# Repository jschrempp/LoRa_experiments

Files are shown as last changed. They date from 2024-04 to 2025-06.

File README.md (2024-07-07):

# LoRa_experiments
## Tests of LoRA module (RYLR998) ranging and low power.

The Reyax RYLR998 is an inexpensive LoRa "modem".  It can perform point to point wireless data communication with other such modules.

The RYLR998 contains both a LoRa chip and a low power microcontroller.  A host microcontroller communicates with an RLYR998 using
serial port "AT" commands, making the RYLR998 very easy to use.  In addition, the RYLR998 has a low power sleep mode that reduces current
draw to about 10 microamps.  The use of LoRa for long distance, low volume data communication along with the ability to sleep the module
when not transmitting suggests that these modules could be ideal for use as long range contact open/close sensors.

The purpose of the tests documented in this repository is to explore the RYLR998 module capabilities in two respects:

- Long range operation:  the ability of the module to successfully commmunicate from an outdoor location some distance from a house
into a receiver located inside of the house.

- Low power operation:  the ability of the module to be powered down when not needed to transmit a short message, in support
of battery powered operation.

There are two main folders in this repository:

- Range_Testing: this folder contains a report and source code for range testing experiments.

- Low_Power_Testing: this folder contains a report and source code for testing low power operation of the module. It also contains
a spreadsheet to calculate battery life, based upon using an Attiny85 as the host microcontroller with a reset pulse generator circuit 
to power it up for transmitting a short message and then powering the LoRa module down and then powering itself down until the next reset.

## LoRa set up ##
- LoRa AT command guide https://lemosint.com/wp-content/uploads/2021/11/Lora_AT_Command_RYLR998_RYLR498_EN.pdf
- LoRa module we use https://reyax.com/products/RYLR498

Note that for these tests you need to program each LoRa module by hand using a terminal emulator and an FTDI module. Connect four
pins from the FTDI to the LoRa module (leave the reset pin on the LoRa module unconnected):

```
FTDI       LoRa
3v3        VDD
TXD        RXD
RXD        TXD
GND        GND
```

Plug the FTDI device into your laptop.

You can use the Arduino IDE Serial Monitor. With the IDE running go to Tools / Port and select the port of your FTDI device (it might be 
something like `/dev/serial-1`). Then click the Serial Monitor button on the upper right of the Arduino IDE. This brings up a new window.
In the bottom menu select "Both NL & CR" and "115200 baud". In the command window at the top type AT and click Send. You should get the 
response +OK

Assuming you are now connected correctly to your LoRa module, perform the following commands:
```
AT+ADDRESS=0
AT+NETWORKID=3
```
Do the same for your second LoRa module.

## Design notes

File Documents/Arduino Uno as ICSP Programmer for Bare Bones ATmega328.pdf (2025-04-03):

# Arduino Uno as ICSP Programmer for Bare Bones ATmega328

By: Bob Glicksman; v1.0; 7/20/24 © 2024, Bob Glicksman, Jim Schrempp, Team Practical Projects. All rights reserved.

Introduction.

This document provides complete instructions for programming a “bare bones” ATmega328 (or ATmega328P) chip using “In Circuit Serial Programming” (ICSP). Bare-Bones means a factory-fresh chip that you will be using:

- With the internal 8 MHz clock (no crystal/capacitors for the external 16 MHz clock used on Uno and other Arduino boards).
- The chip does not come with a bootloader already flashed onto it.

The Arduino IDE (version 1.8.7) is used for both software development and for uploading compiled code to the chip. An Arduino Uno (R3) is used as the hardware ICSP programmer.

The information herein is based upon the official Arduino documentation that can be found at: https://docs.arduino.cc/built-in-examples/arduino-isp/ArduinoToBreadboard/

The Arduino documentation focuses on the use of ICSP to upload the Arduino bootloader to the bare bones chip. Thereafter, user-created programs are uploaded to the chip using the bootloader. This document describes a procedure that uses ICSP exclusively and overwrites the bootloader. There are several reasons for our wanting to do this:

- The bootloader takes up 512 bytes of the 32 Kbytes of flash memory on the ATmega328 chip. This is small and usually unimportant.
- When the bootloader is used, resetting the ATmega328 executes the bootloader first. When no new code is available for uploading (particularly when no programmer is attached to the chip’s serial I/O port), the bootloader times out before transferring control to the existing user’s program. The timeout delay is short, however this delay can be important for applications that are battery powered and use RESET to wake up from deep sleep, perform a small function, and then go back to deep sleep. Adding bootloader execution time to the regular wakeup execution time can significantly add to battery drain.
- The bootloader uses the (single) hardware serial port on the ATmega328. If the user’s application also uses the serial port, there can be a conflict if the chip is to be programmed in-circuit. Extra components will be necessary in the circuit to allow both an external serial programmer and the internal (to the project) circuitry to use the one hardware serial port without conflict.

This document describes the procedure to upload code to both the ATmega328 and the ATmega328P chips. The -P version of the chip can be powered down to a much lower power draw then the non-P version (< ⅓ microAmp as opposed to about 25 microAmps). The -P version also has a few more machine language instructions than does the non-P version, but this does not seem to make any difference when programming in the Arduino programming language (“Wiring”) using the Arduino IDE.

Hardware Requirements.

The following hardware is needed for this project:

- 1 ea. Arduino Uno (R3), or clone.
- 1 ea. Solderless breadboard.
- 2 ea. 0.1 uF decoupling capacitors.
- Male-male jumper wires
- ATmega328-PU or ATmega329P-PU microcontroller chips (without bootloader):
- non-P version: Digikey P/N ATMEGA328-PU-ND
- -P version: Digikey P/N ATMEGA328P-PU-ND
- (optional) 28 pin, 0.3” ZIF socket: Adafruit P/N 382
- (optional) 3 ea LED and 3 ea resistor (220 or 330 ohm) – wire per the instructions in the comments in the ArduinoISP program if you want these status indicators.

# Hardware Setup for Using Uno as ISP Using ICSP

Protocol.

The following figure shows how to wire an Arduino Uno to the breadboard in order to use it as an ISP. This figure is taken directly from the official Arduino documentation:

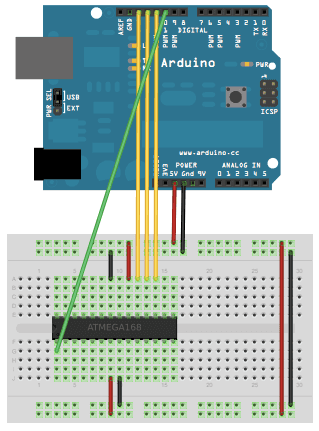
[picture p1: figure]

Here are the instructions:

1. Wire the breadboard power rails: Wire the + power bus on one side of the breadboard to the + power bus on the opposite side of the breadboard.
2. Wire the breadboard ground rails: Wire the - (gnd) power bus on one side of the breadboard to the - (gnd) power bus on the opposite side of the breadboard.
3. Wire the Uno GND pin to the closest - (gnd) power bus on the breadboard
4. Wire the Uno +5 volt power pin to the closest + power bus on the breadboard.
5. Place the target ATmega328 or ATmega328P chip on the breadboard, as shown in the diagram. OPTIONALLY, place a 28 pin ZIF socket where the ATmega is shown. Note that in the diagram above, ATmega pin 1 (notch at the top of the chip) is to the left.
6. Wire IC pin 7 to the closest + power rail.
7. Wire IC pin 8 to the closest - (gnd) power rail.

8. Place a 0.1 uF decoupling capacitor between IC pins 7 and 8, close to the power wiring to the chip.
9. Wire IC pin 20 to the closest + power rail.
10. Wire IC pin 22 to the closest - (gnd) power rail.
11. Place a 0.1 uF decoupling capacitor between IC pins 20 and 22, close to the power wiring to the chip.
12. Wire Uno digital pin 10 to pin 1 of the IC on the breadboard.
13. Wire Uno digital pin 11 to pin 17 of the IC on the breadboard.
14. Wire Uno digital pin 12 to pin 18 of the IC on the breadboard.
15. Wire Uno digital pin 13 to pin 19 of the IC on the breadboard.

TIP: If using the ZIF socket, then with a Sharpie marker, put four marks on the ZIF case at the pin position for each of the ends of the ZIF socket. This makes it easier to map ATmega chip pins to the solderless breadboard wire holes.

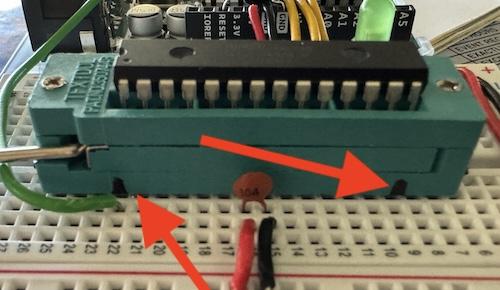
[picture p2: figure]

Overview of Operating Instructions.

Detailed operating instructions are presented in the next section of this document. Here is an overview of the entire process:

1. Install a “hardware/breadboard” folder into your Arduino Uno IDE sketchbook. This folder is necessary to tell the IDE about the chip that you are going to program. Optionally edit the file “boards.txt” to change from the default -P chip to the non-P version of the chip.

2. Open the Arduino IDE and upload the example sketch “ArduinoISP” to your Uno board. This makes your Uno into an ICSP programmer for your bare bones chips, using the wiring described above.
3. Flash the Arduino bootloader to the ATmega328(P).
4. Configure the Arduino IDE for programming the bare bones chip.
5. Compile and verify your program on the Arduino IDE.
6. Upload your program to the bare bones chip using ICSP.

NOTE: This procedure will flash the Arduino bootloader to the bare bones chip but will subsequently overwrite it. You need to flash the bootloader because this process also sets necessary fuses and locks on the bare bones chip. After executing this procedure in full the first time, you can skip steps 1-3 thereafter, as the fuses and locks will remain properly set. The bootloader program itself will be overwritten, but it is not needed when using this procedure. You can, however, always restore the bootloader to the bare bones chip by following steps 1-3 of this procedure.

Detailed Operating Instructions.

This section provides step by step detailed instructions for each of the steps listed above.

## 1. Install the “hardware/breadboard” folder into your Arduino

sketchbook.

You can find the location of your Arduino sketchbook using the Arduino IDE. Open the IDE and select “File : Preferences”. You will see the location of your sketchbook here:

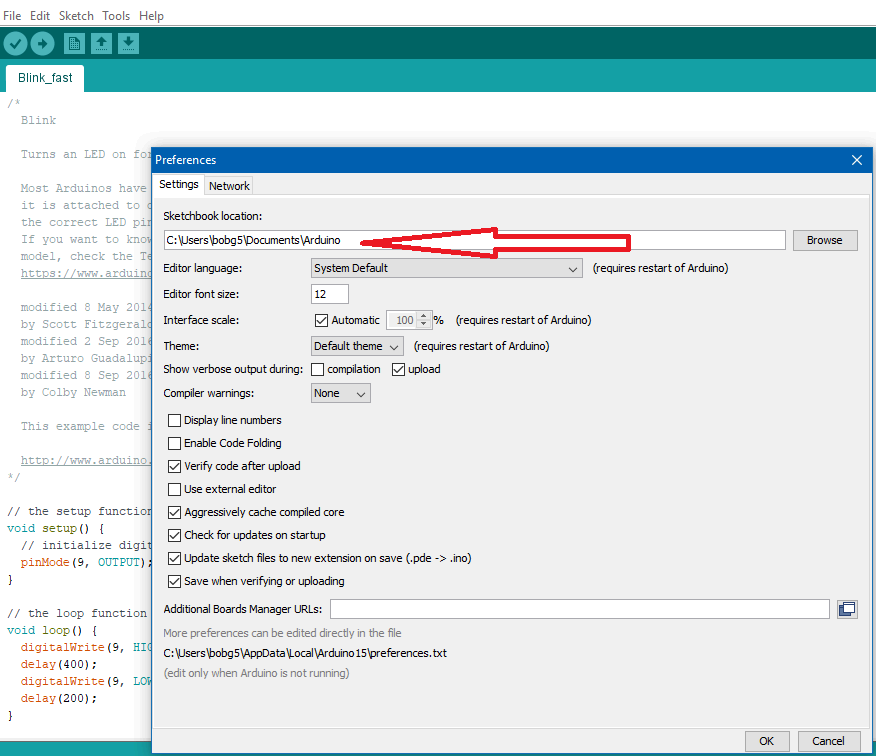
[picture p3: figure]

Open the sketchbook location on your computer using your computer’s file explorer. See if there is already a folder called “hardware” here. If not, create an empty folder called “hardware”.

Download the following zip file from the Arduino website: https://www.arduino.cc/en/uploads/Tutorial/breadboard-1-6-x.zip

Open this zip file and extract the contents. The contents will be a folder called “breadboard” with some subfolders and other files inside of it. Drag and drop the “breadboard” folder inside of the “hardware” folder in your Arduino sketchbook.

If you plan to use only the -P chips, then you don’t need to do anything else in this step. If you plan to use non-P chips, follow these additional steps:

- Open the “breadboard” folder that you just installed into the “hardware” folder in your Arduino sketchbook location.
- Open the “avr” folder.
- Open the file “boards.txt” in any text editor (e.g. Notepad on a Windows PC). It will look like the following figure:

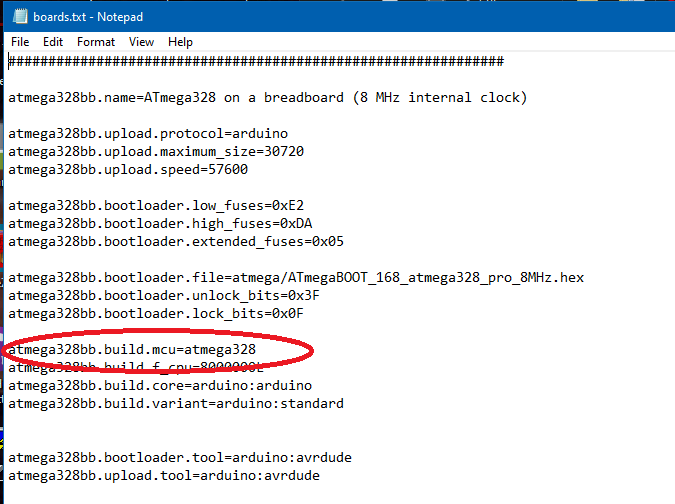
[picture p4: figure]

Note the circled line in the figure. The downloaded file will say “atmega328bb.build.mcu=atmega328p”. Note the “p” at the end of this line. This tells the Arduino IDE that the bare bones chip will be an ATmega328P chip. Remove the “p” at the end of this line (as shown in the figure) if you want to upload code to non-P chips. SAVE the edited file and exit your text editor.

## 2. Upload “ArduinoISP” Code to Your Uno to Make It Into An

In-System Programmer (ISP).

Open your Arduino IDE. If it is already open, you must close it and open it again.

As an optional first step, we recommend that you enable “verbose” status on the IDE when uploading code. Open the Arduino IDE preferences and check the “upload” check box, as shown in the figure below. Then click “OK” to exit the preferences.

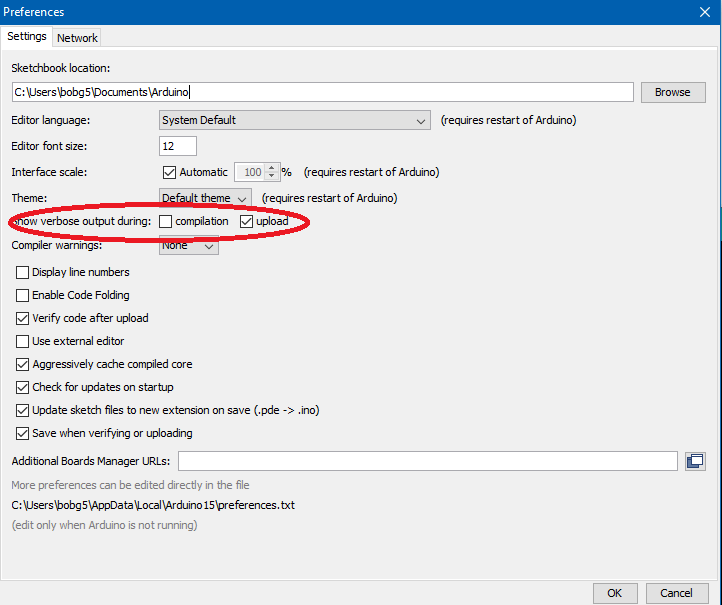
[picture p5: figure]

Next, you need to load the file “ArduinoISP” into the IDE, see the figure below. Select “File: Examples:11. ArduinoISP: ArduinoISP”. The IDE code window will show the source code for the Example file called “ArduinoISP”.

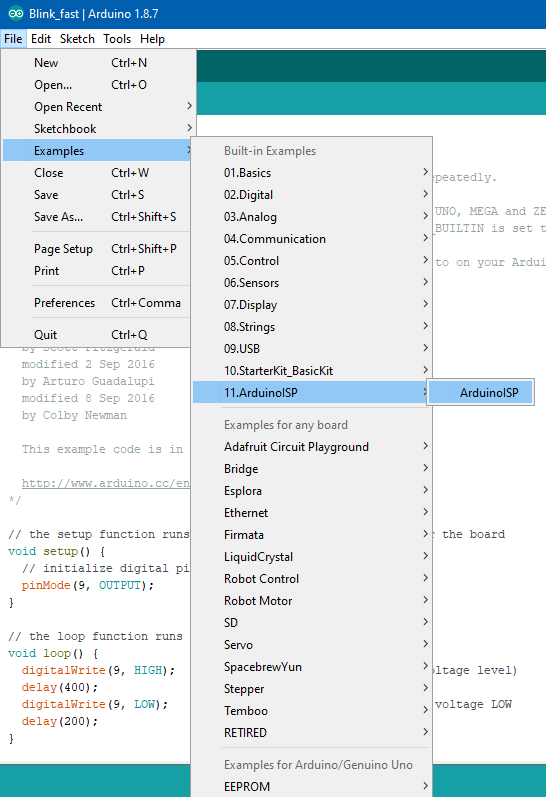
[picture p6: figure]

Before compiling and uploading “ArduinoISP” to your Uno board, make sure that your Tools settings are correct, see figure below:

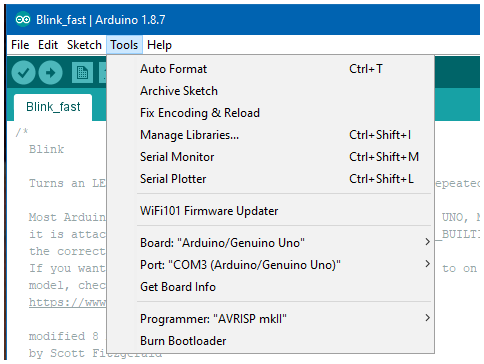
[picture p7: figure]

Note the following in this figure:

- The “Board:” must be “Arduino/Genuino Uno”
- The “Port” will be the COM or tty port that your Uno is connected to (may not be COM 3, as in the above figure).
- The “Programmer” must be set to “AVRISP mkII”.

After double checking these Tools settings, click on the Compile and Upload button: the Right facing arrow at the top left of the IDE window. This will flash the ArduinoISP code to your Uno. NOTE: You only need to do this once - thereafter, the ArduinoISP code will be running when you power up your Uno (unless you change it, of course).

3. Flash the Arduino Bootloader to the Bare Bones Chip.

You must next flash the Arduino bootloader to the bare bones chip. This step is necessary because it sets fuses and locks on the bare bones chip that are needed for the chip to operate properly. This step will also flash the bootloader program to your bare bones chip, but the bootloader will be overwritten in the subsequent steps of this procedure.

MAKE SURE THAT YOU HAVE YOUR BARE BONES CHIP PROPERLY INSERTED INTO YOUR BREADBOARD OR ZIF SOCKET. MAKE SURE THAT THE WIRING FROM THE UNO TO YOUR BREADBOARD IS CORRECT! MAKE SURE THAT YOU HAVE SET YOUR

BOARD.TXT FILE TO THE CORRECT CHIP (-P or non-P) PER THE FIRST STEP IN THIS DETAILED PROCEDURE.

Open the “Tools” menu on the Arduino IDE and go to “Board:” Look down the drop-down list for “ATmega328 on a breadboard (8 MHz internal clock)”, as shown in the figure below. Select “ATmega328 on a breadboard (8 MHz internal clock)” as the board to be programmed.

NOTE: if you don’t see this option, then go back to the initial step of this procedure where you installed the “hardware/breadboard” folder into your sketch folder using the downloaded zip archive. Repeat the steps, close the Arduino IDE and then reopen it. You should now see this Board option in your “Tools:Board” list.

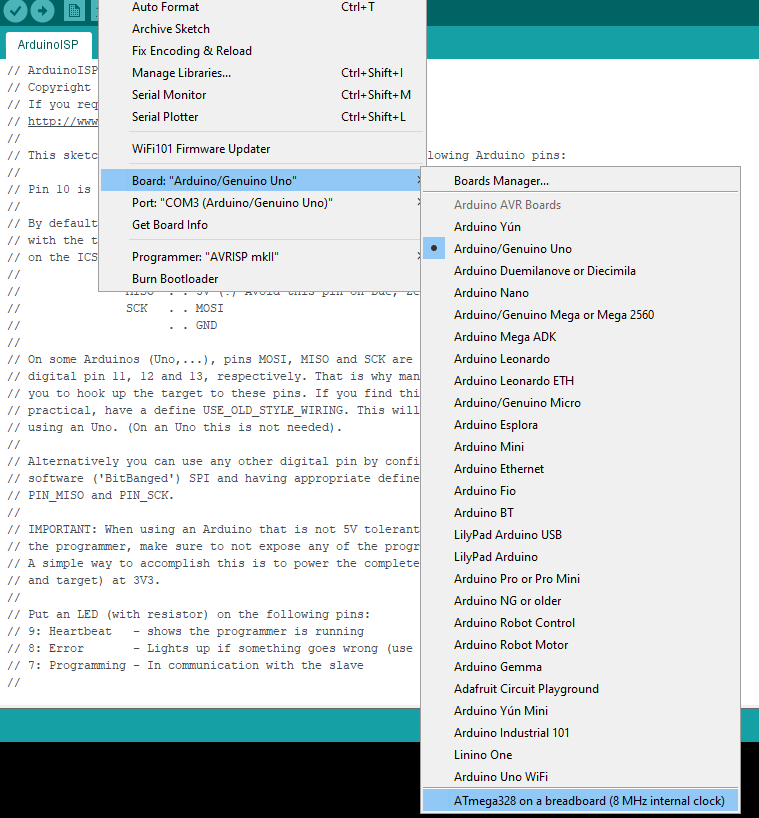
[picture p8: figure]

Next, go to “Tools” again and change the “Programmer” setting to “Arduino as ISP”

NOTE: do NOT confuse this with “ArduinoISP” which is also shown on the dropdown list. “ArduinoISP” is the program that you uploaded to your Uno in the previous step. In this step, you are selecting “Arduino as ISP” which tells the IDE to use your Uno as a programmer, rather than flashing new code to it.

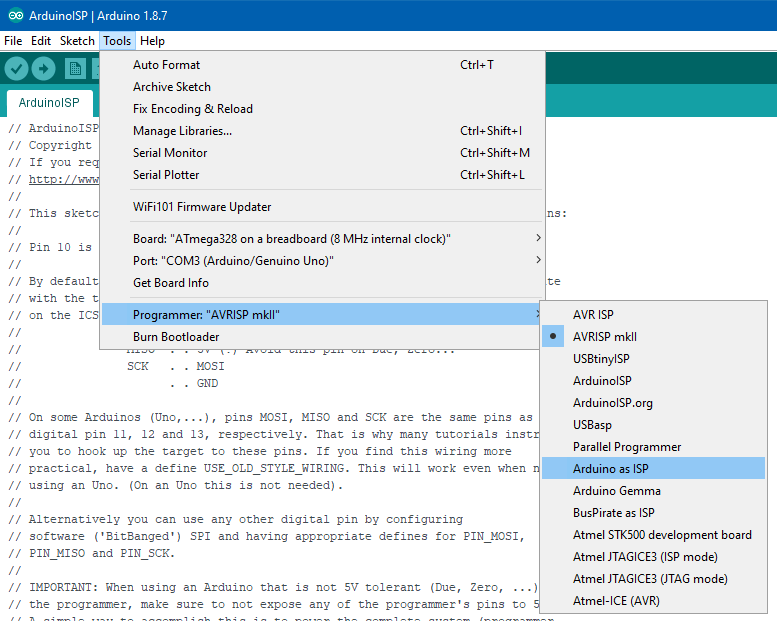
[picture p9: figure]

Before proceeding, verify all of your IDE settings, as in the figure below:

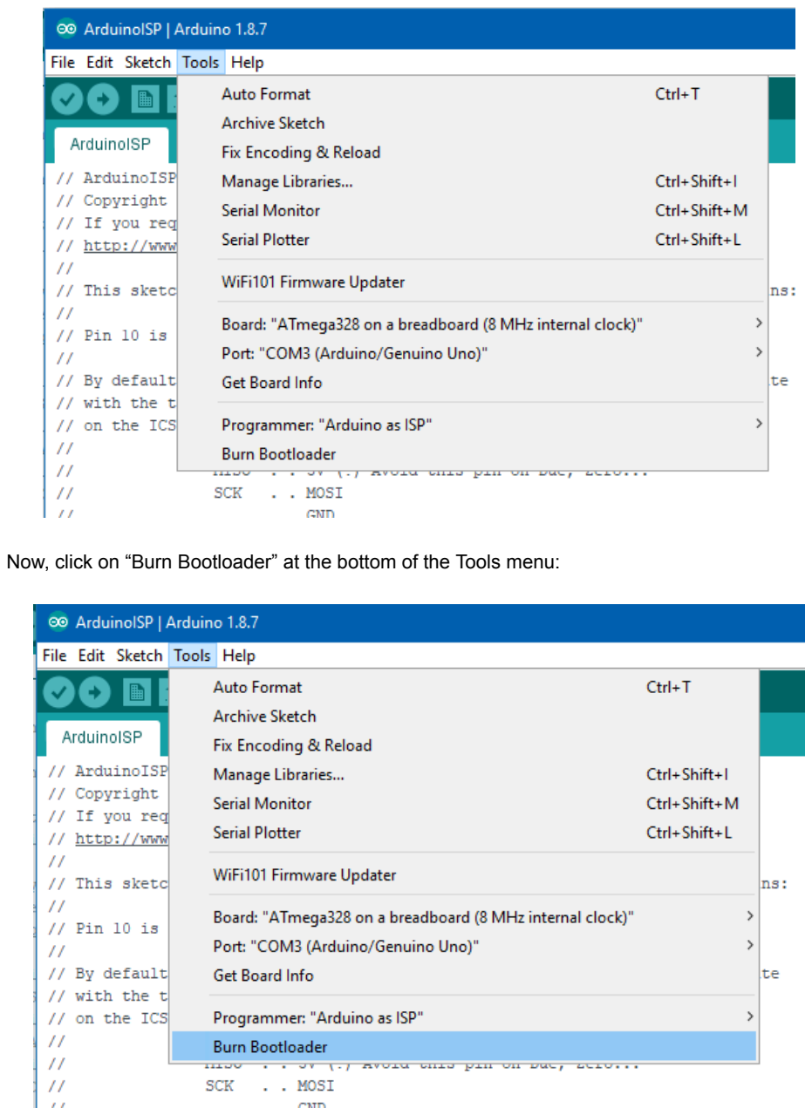
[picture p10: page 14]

Now, click on “Burn Bootloader” at the bottom of the Tools menu:

You will see the lights on the Uno flash for a bit while the fuses, locks and bootloader code are uploaded to your bare bones chip.

NOTE: if you get a signature error in the IDE status window, then you are probably configured for the wrong version of the ATmega328 chip (-P or not -P). Go back to the first step in this procedure and check the indicated line in the “boards.txt” file. Make the correction, save the file, close and open the IDE, and repeat this step.

## 4. Configure the Arduino IDE for ICSP Programming of a Bare

Bones Chip.

You should have the proper settings in the Tools menu, but you should verify this, as in the figure below:

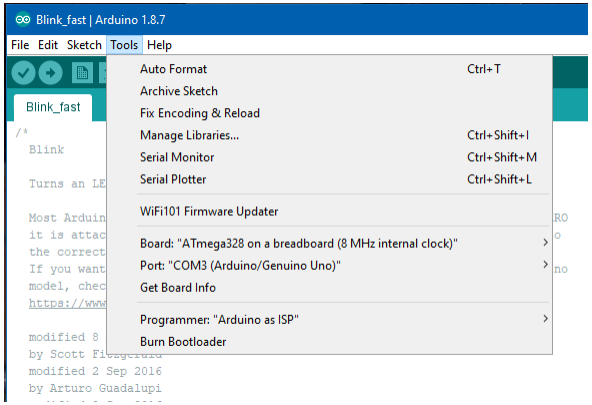
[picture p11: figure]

Double-check the following:

- “Board: ATmega328 on a breadboard (8 MHz internal clock)”
- “Port:” The COM or tty port that your Uno is connected to.
- “Programmer:” “Arduino as ISP”.

5. Compile and Verify Your Program on the Arduino IDE.

You are now ready to open or create a new program of your own that you want to upload to the bare bones chip. Proceed as you would for any program that you import, select, or create on the Arduino IDE. When your program is ready, you can compile and verify (but NOT upload) your code. You do this by clicking on the CHECK icon at the top left of the IDE (NOT the right arrow icon!), as shown in the figure below:

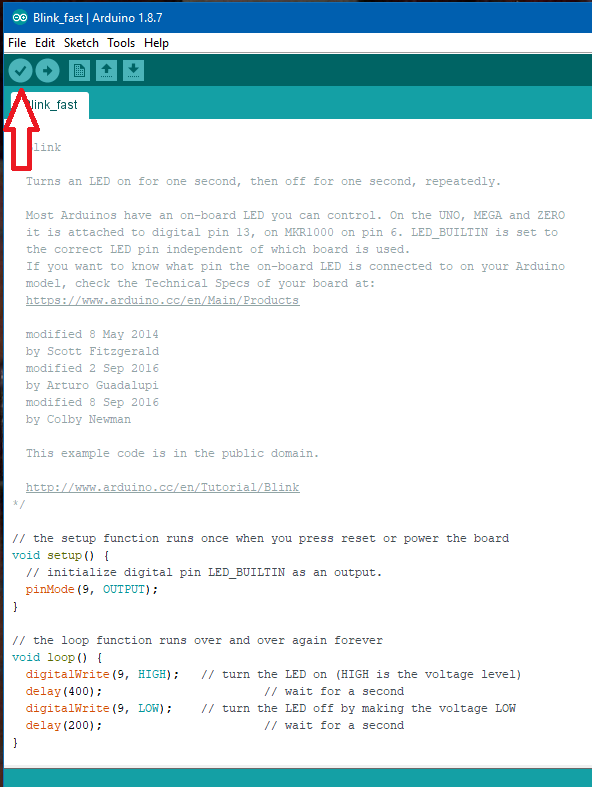
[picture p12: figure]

Check the status window on the IDE to make sure that your code has compiled and verified correctly!

6. Upload Your program to the Bare Bones Chip.

In order to upload your program to the bare bones chip using ICSP, you must open the “Sketch” menu on the Arduino IDE and select “Upload Using Programmer”:

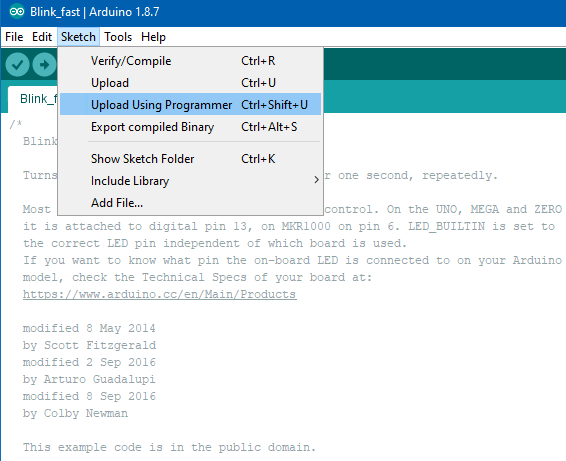
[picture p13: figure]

After a short delay, you will see lights flashing on the Uno indicating that it is working as an ICSP programmer and uploading your sketch to the bare bones chip.

At this point the ATmega will be executing code while in the programmer. One tip is to attach and LED and appropriate resistor to one digital pin and have your setup() code blink this once. That way you can verify in the programmer that your download has worked.

Subsequent Uploads to the Bare Bones Chip.

Once you have successfully completed all of these steps, you need not repeat steps 1-3 in order to modify the code and upload it to this same chip. You only need to perform steps 4 - 6, unless you (a) change the code flashed to your Uno, or (b) wish to restore the bootloader to your bare bones chip or (c) wish to upload code to another factory-fresh chip.

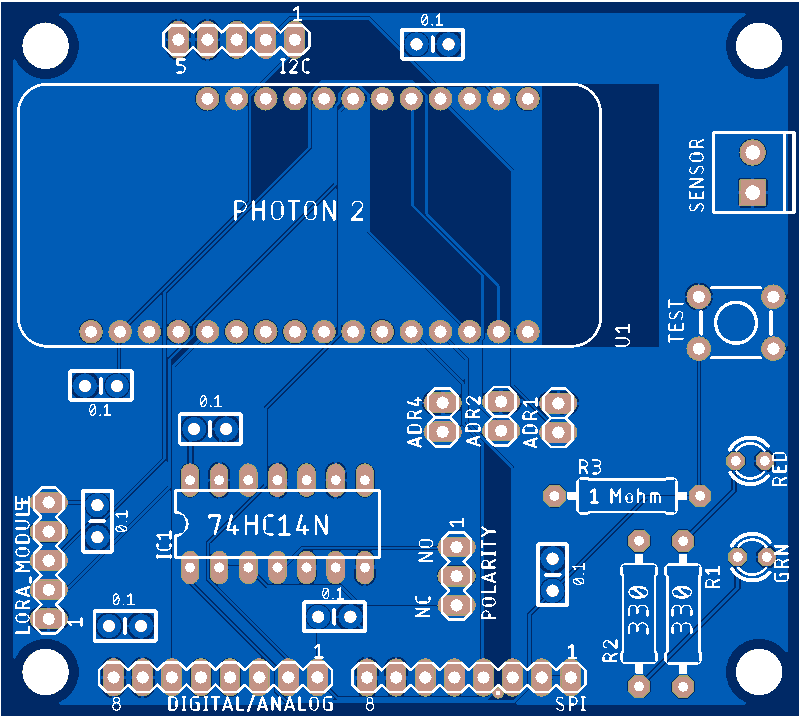
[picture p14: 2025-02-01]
Hardware/LoRa Photon 2 PCB/LoRa_Photon2/LoRa_Photon_2_pcb.png

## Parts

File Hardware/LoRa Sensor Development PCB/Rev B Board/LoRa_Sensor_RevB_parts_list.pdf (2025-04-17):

ITEM | PART NUMBER | MFG OR URL | DESCRIPTION | QTY | UNIT COST EXTENDED COST | NOTES | BG INV
1 Y10-2800069A | JLCPCB | Rev B PCB | 1 | $1.55 | $1.55 10 more boards on order 4/15/25 | 5

### 2 ATMega328P

https://www.digikey.com/en/products/detail/micro
chip-technology/ATMEGA328P-PU/1914589 | Microcontroller, 28 pin DIP | 1 | $2.89 | $2.89

I also have 5 non-P versions -- slightly higher
power but they work fine. | 4

### 3 Socket, 28 pin

https://www.amazon.com/uxcell-2-54mm-7-62mm-Soldering-Adaptor/dp/B07H3RP3JV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 En1ThlboPaV3COU4RK2hHrZodWnQ5sTGnGz4HQd hPUHrRxw2KXfZdHgG2wrHfeWkLYs1MahEdmNyZk X5PDTyATmnODv6ZC8hCcJhAyFBERcQ0ddlxnjp02lr vBw1igXjTKa5hQ.5xl5LLIRF56biPLH8kMX2m6P4R6x
adWV7I_maik6qSE&dib_tag=se&keywords=28+pin+
DIP+socket&qid=1744761481&sprefix=28+pin+dip+
socke%2Caps%2C183&sr=8-5 | 28 pin DIP socket | 1 | $0.33 | $0.33 URL is for 20 pcs | 5

4 74HC14N

https://www.digikey.com/en/products/detail/texas-
instruments/SN74HC14N/277223 | Hex CMOS inverter | 1 | $0.89 | $0.89 | 3

### 5 Socket, 14 pin

https://www.amazon.com/uxcell-2-54mm-Soldering-Socket-Adaptor/dp/B07H3WQYRQ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 EALaU3pVoE1LwHUuFkKhaxR6vCGmxljUArKusNRUKvnl A-VRif2UGHYDCarszrOfulmSilFftBcoGowjmH3BneBfIw08VRZCU3pqD1gH5IPZfksUx-Th7oCVgRJOAkPr0ZbPxcMwBGcvB7RXs0kBuCuzddkaqe6pv aMmh19ilpAqmxtK9S_RUCmzYH04kI61MIibgpgspT ph-lE0pbnwvU.icjyUkQsbgvTHvpMFriUBUrfxbnpt2abpGHPsOCUZE&dib_tag=se&keywords=14
+pin+DIP+socket&qid=1744761619&sprefix=14+pin
+dip+socket%2Caps%2C251&sr=8-3 | 14 pin DIP socket | 1 | $0.17 | $0.17 URL is for 40 pcs | 10

### 6 RYLR998

https://www.amazon.com/dp/B099RM1XMG?ref=p
px_yo2ov_dt_b_fed_asin_title | LoRa module, 915 MHz | 1 | $12.60 | $12.60 | 1

7 5 pin connector

https://www.amazon.com/Female-Headers-2-
54mm-Single-Connector/dp/B08T67RT8P/ref=sr_1_6?contentid=amzn1.sym.a076e7cd-4184-4b7f-a3aa-6a57a7570e58%3Aamzn1.sym.a076e7cd-4184-4b7f-a3aa-6a57a7570e58&dib=eyJ2IjoiMSJ9.W0noIfqcsOvUCs RPRRwNZXfyVjreQHL2MNQAJ4EujfEkHLjPAUFYlhJwSAAT Oqw8tPRzNHcji0S_ZDAC5sETtHQPYatDXWzzP7P4B gHGg5l8uANKXhAUtszp2dP-MSwPQGuekF0jzxb9frhymrgfgJAwerDD5t4o_6dezPi Po7uDH6ar0UxLD-688zKDWwRoDLLgyDu0ViZzyx46xEN1_ptV63gkwGy 0X4fQwhRq40kiiDrP_8gAjmt33lLFC4DRuA97B2REgj vWvVZkhVm77EkzLJznpqx-FmnRxQLEIo.TXHj_w6KZu4A8kWZA_GLvX_sk5QCdv BXxqjOEC565O0&dib_tag=se&keywords=5+pin+fe male+pin+header&pd_rd_r=d9221ee6-2e27-42cbb58cec69ec3b9ae2&pd_rd_w=Hnlr6&pd_rd_wg=DlvLf&q
| id=1744762468&sr=8-6 | 5 pin female header, 90 degree | 1 | $0.16 | $0.16 URL is for 50 pcs | 35
8 terminal block, 2 pin | https://www.adafruit.com/product/724 | 2 pin, 3.5 mm terminal block | 2 | $0.59 | $1.18 URL is for 5 pcs | 7
9 pcb switch | https://www.amazon.com/dp/B0DR2DPW59?ref=p
| px_yo2ov_dt_b_fed_asin_title&th=1 | pcb slide switch | 1 | $0.09 | $0.09 URL is for 80 switches | 50

### 10 pushbutton switch

Momentary-Tactile-Quality/dp/B01CGMP9GY/ref=sr_1_3?crid=1BT75H
D7EH7HV&dib=eyJ2IjoiMSJ9.JlRdu5IIhRb13BSG3- SPDT slide switch, 0.1 mm pitch | 2 | $0.05 | $0.11 URL is for 100 pcs | 30

### 11 male pin header

https://www.amazon.com/dp/B07R5QDL8D?ref=pp
x_yo2ov_dt_b_fed_asin_title

breakable male pin header, 40 pins, 2.54
| mm | 1 | $0.27 | $0.27 URL is for 20 strips, 40 pins each | 10

### 12 resistor, I Mohm

https://www.digikey.com/en/products/detail/stackp
ole-electronics-inc/CF14JT1M00/1741316 | 1 Mohm, 1/4W, through hole resistor | 1 | $0.10 | $0.10 | 5

### 13 resistor, 1 Kohm

https://www.digikey.com/en/products/detail/stackp
ole-electronics-inc/CF14JT1K00/1741314 | 1 Kohm, 1/4W, through hole resistor | 1 | $0.10 | $0.10 | 40

### 14 Red LED

https://www.amazon.com/Diode-Lights-120Pcs-Emitting-Assorted/dp/B0BY28JTFC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 Vkps4ikE12tjY0yF9U90AnTv6m9tKwqCMe8F2cgYOqu5T 5sBXjVYDNlY-SFkwtYLqvDdHWdlT6CYg4kvRYuNBcZLlcU0hRjYm3nSuWYLFPttIyTpxvkG3-yLnN6QtUinsVpc.4ApmabSVR-ZXlwQNI7db_pofeoIZTkJ5VvqVkDeOvY&dib_tag=se&keywords=red%2Bled%2B3mm&qi
d=1744762661&sprefix=red%2Bled%2B3mm%2Ca
| ps%2C200&sr=8-3&th=1 | Red LED, 3 mm | 1 | $0.04 | $0.04 URL is for 120 pcs | 20
15 Backlit pushbutton | https://www.adafruit.com/product/1440 | Green backlit pushbutton switch, panel
| | mount | 1 | $1.50 | $1.50 | 1
16 resistor, 330 ohm | https://www.digikey.com/en/products/detail/stackp
| ole-electronics-inc/CF14JT330R/1741399 | 330 ohm, 1/4W, through hole resistor | 2 | $0.10 | $0.20 | 11
17 capacitor, 100 uF | https://www.digikey.com/en/products/detail/rubyc
| on/35YXJ100M6-3X11/3563127 | 100 uF electrolytic capacitor, 10 volt | 1 | $0.20 | $0.20 | 20
18 capacitor, 0.1 uF | https://www.adafruit.com/product/753 | 0.1 uF ceramic capacitor, PCB | 10 | $0.20 | $1.95 URL is for 10 pcs | 11

### 19 battery holder

https://www.amazon.com/10Pcs-Battery-Holder-CR123A-Lithium/dp/B08RD1KQN3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 eH0mKLAfZkvZeiQh5MNyiY9QoTH6TeCB9N3-LZTDB4RAYLVbziLai-Lr8yBbOeQdnmwxl3hHAXRxzl58-XKznDxlBYJF7HMNiy2viXwkWCiiVrFQpaQjiLYxe83z9 kGSFdi18mduijg.MOh2SZFfu496f5C8bGMVPcgcCGmM5M
Koxda1s8jlcvs&dib_tag=se&keywords=123A+batter
y+holder&qid=1744762563&sprefix=123a+battery+
holder%2Caps%2C188&sr=8-1 | PCB battery holder for 123A battery | 1 | $0.80 | $0.80 URL is for 10 pcs | 5

### 20 battery, 3 volts

https://www.amazon.com/dp/B08YJQYD5Z?ref=ppx
_yo2ov_dt_b_fed_asin_title&th=1 | CR123A lithium 3 volts battery. | 1 | $1.97 | $1.97 URL is for 4 batteries | 1
TOTAL = | $27.10

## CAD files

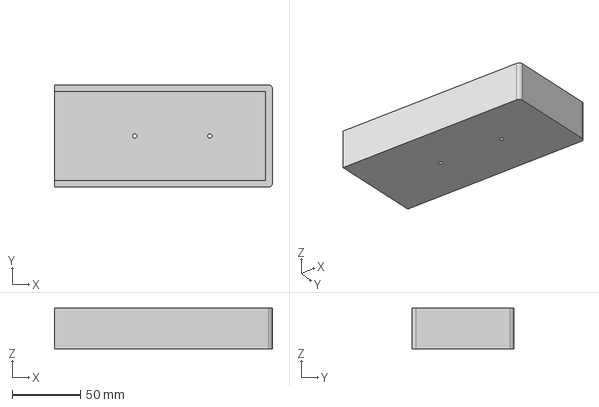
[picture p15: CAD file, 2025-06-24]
Hardware/Help Button Case/Wall Mount-2025-04-25-1.step
160.0 x 75.0 x 30.0 mm

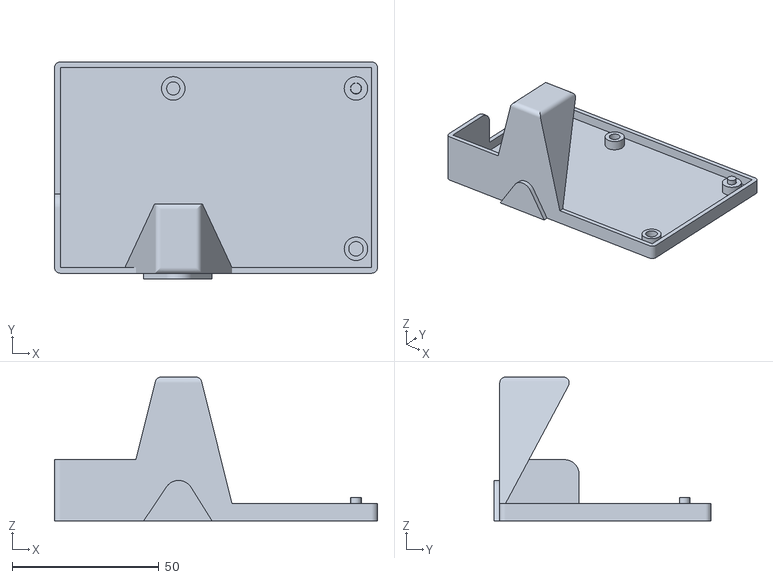
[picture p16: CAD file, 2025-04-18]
Hardware/Hub Case/LoRaHubCase.stl
110.0 x 74.0 x 49.0

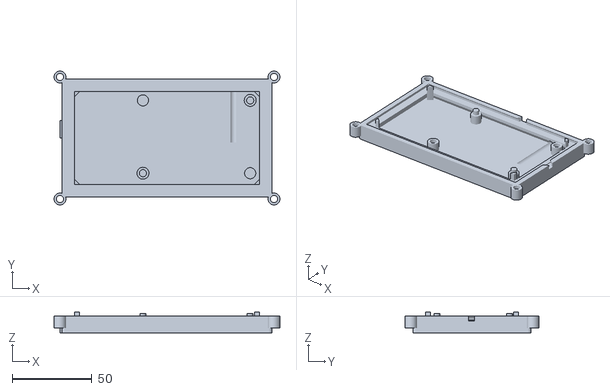
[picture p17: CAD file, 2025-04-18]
Hardware/Sensor Case/Bottom square.stl
141.8 x 84.1 x 13.0

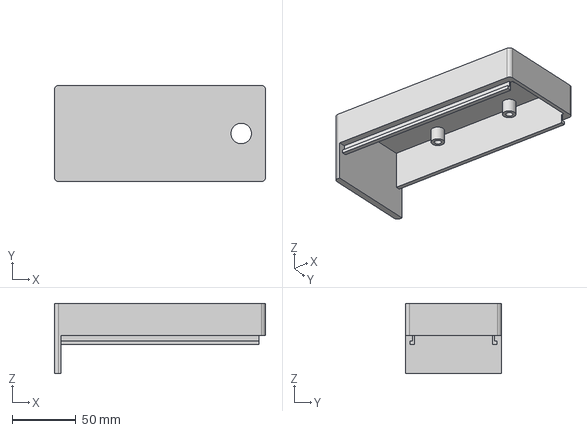
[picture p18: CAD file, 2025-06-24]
Hardware/Help Button Case/PCB Mount-2025-04-25-1.step
165.0 x 75.0 x 55.0 mm

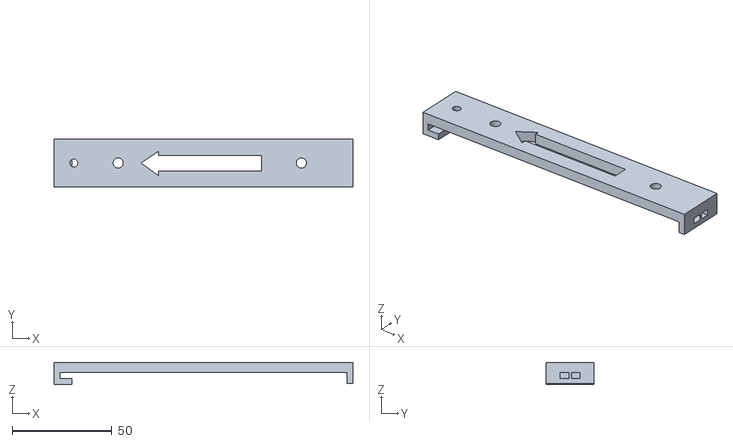
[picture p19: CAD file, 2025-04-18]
Hardware/Sensor Case/bracket.stl
150.0 x 24.0 x 11.2

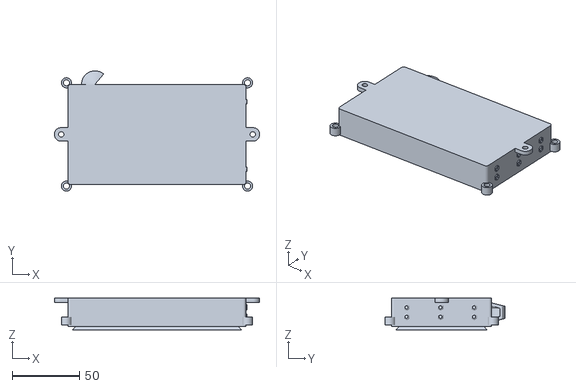
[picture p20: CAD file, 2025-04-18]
Hardware/Sensor Case/Top.stl
152.0 x 89.2 x 23.4

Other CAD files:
Hardware/Hub Case/LoRa_Hub_Case.f3d
Hardware/Sensor Case/LoRa_Sensor_Waterproof.f3d

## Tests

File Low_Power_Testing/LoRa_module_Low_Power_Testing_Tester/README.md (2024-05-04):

# Low_Power_Testing_Tester

This firmware project was created using [Particle Developer Tools](https://www.particle.io/developer-tools/) and is compatible with all [Particle Devices](https://www.particle.io/devices/).

Feel free to replace this README.md file with your own content, or keep it for reference.

## Table of Contents
- [Introduction](#introduction)
- [Prerequisites To Use This Template](#prerequisites-to-use-this-repository)
- [Getting Started](#getting-started)
- [Particle Firmware At A Glance](#particle-firmware-at-a-glance)
  - [Logging](#logging)
  - [Setup and Loop](#setup-and-loop)
  - [Delays and Timing](#delays-and-timing)
  - [Testing and Debugging](#testing-and-debugging)
  - [GitHub Actions (CI/CD)](#github-actions-cicd)
  - [OTA](#ota)
- [Support and Feedback](#support-and-feedback)
- [Version](#version)

## Introduction

For an in-depth understanding of this project template, please refer to our [documentation](https://docs.particle.io/firmware/best-practices/firmware-template/).

## Prerequisites To Use This Repository

To use this software/firmware on a device, you'll need:

- A [Particle Device](https://www.particle.io/devices/).
- Windows/Mac/Linux for building the software and flashing it to a device.
- [Particle Development Tools](https://docs.particle.io/getting-started/developer-tools/developer-tools/) installed and set up on your computer.
- Optionally, a nice cup of tea (and perhaps a biscuit).

## Getting Started

1. While not essential, we recommend running the [device setup process](https://setup.particle.io/) on your Particle device first. This ensures your device's firmware is up-to-date and you have a solid baseline to start from.

2. If you haven't already, open this project in Visual Studio Code (File -> Open Folder). Then [compile and flash](https://docs.particle.io/getting-started/developer-tools/workbench/#cloud-build-and-flash) your device. Ensure your device's USB port is connected to your computer.

3. Verify the device's operation by monitoring its logging output:
    - In Visual Studio Code with the Particle Plugin, open the [command palette](https://docs.particle.io/getting-started/developer-tools/workbench/#particle-commands) and choose "Particle: Serial Monitor".
    - Or, using the Particle CLI, execute:
    ```
    particle serial monitor --follow
    ```

4. Uncomment the code at the bottom of the cpp file in your src directory to publish to the Particle Cloud! Login to console.particle.io to view your devices events in real time.

5. Customize this project! For firmware details, see [Particle firmware](https://docs.particle.io/reference/device-os/api/introduction/getting-started/). For information on the project's directory structure, visit [this link](https://docs.particle.io/firmware/best-practices/firmware-template/#project-overview).

## Particle Firmware At A Glance

### Logging

The firmware includes a [logging library](https://docs.particle.io/reference/device-os/api/logging/logger-class/). You can display messages at different levels and filter them:

```
Log.trace("This is trace message");
Log.info("This is info message");
Log.warn("This is warn message");
Log.error("This is error message");
```

### Setup and Loop

Particle projects originate from the Wiring/Processing framework, which is based on C++. Typically, one-time setup functions are placed in `setup()`, and the main application runs from the `loop()` function.

For advanced scenarios, explore our [threading support](https://docs.particle.io/firmware/software-design/threading-explainer/).

### Delays and Timing

By default, the setup() and loop() functions are blocking whilst they run, meaning that if you put in a delay, your entire application will wait for that delay to finish before anything else can run. 

For techniques that allow you to run multiple tasks in parallel without creating threads, checkout the code example [here](https://docs.particle.io/firmware/best-practices/firmware-template/).

(Note: Although using `delay()` isn't recommended for best practices, it's acceptable for testing.)

### Testing and Debugging

For firmware testing and debugging guidance, check [this documentation](https://docs.particle.io/troubleshooting/guides/build-tools-troubleshooting/debugging-firmware-builds/).

### GitHub Actions (CI/CD)

This project provides a YAML file for GitHub, automating firmware compilation whenever changes are pushed. More details on [Particle GitHub Actions](https://docs.particle.io/firmware/best-practices/github-actions/) are available.

### OTA

To learn how to utilize Particle's OTA service for device updates, consult [this documentation](https://docs.particle.io/getting-started/cloud/ota-updates/).

Test OTA with the 'Particle: Cloud Flash' command in Visual Studio Code or the CLI command 'particle flash'!

This firmware supports binary assets in OTA packages, allowing the inclusion of audio, images, configurations, and external microcontroller firmware. More details are [here](https://docs.particle.io/reference/device-os/api/asset-ota/asset-ota/).

## Support and Feedback

For support or feedback on this template or any Particle products, please join our [community](https://community.particle.io)!

## Version

Template version 1.0.2

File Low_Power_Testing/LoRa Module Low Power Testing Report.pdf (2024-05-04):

# LoRa Module Low Power Testing Report

By: Bob Glicksman; 5/04/24
OVERVIEW.

This document describes the low power mode tests performed on the RYLR998 LoRa modules (https://reyax.com/products/RYLR998). These tests were performed in order to verify that these modules can be powered down to under 10 microamps when not being used to transmit data. Specifically, these tests verified that the modules can be powered up, then transmit a short message and then be powered down. This operation is necessary for a battery powered sensor, such as needed for the IVGM project.

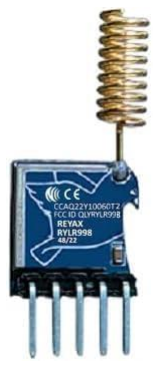
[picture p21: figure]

Figure 1. RYLR998 LoRa Modem Module.
RESULTS.

The RYLR998 LoRa modules were measured to draw about 17.5 milliamps when receiving (mode = 0) and about 8.5 microamps when in low power mode (mode = 1). When switching from mode 0 to mode 1, the module returns “+OK/r/n” and then powers down. When powered down, switching back to mode 0 returns “+OK/r/n” and the module powers up. Note that when in low power mode, sending a message (e.g. “AT+SEND=1,5,HELLO”) powers the module back up but returns “+MODE=0” as opposed to “+OK”. We think it best to explicitly power the LoRa module up before sending a message.

TESTING METHODOLOGY.

Mode and Power Testing.

An FTDI module was directly wired to an RYLR998 module as follows:

- FTDI GND to RYLR998 GND
- FTDI +3.3 to ammeter + (multimeter); ammeter – to RYLR998 VDD
- FTDI Tx to RYLR998 RXD
- FTDI Rx to RYLR998 TXD
- FTDI +5 unconnected
- RYLR998 NRST unconnected
The Arduino IDE Serial Monitor was used for communication. The current draw from the +3.3 volt power was measured by the multimeter on the 20 ma scale and also on the 200 microamp scale (lowest current scale available). The Serial Monitor was set to the RYLR998 default baud rate of 115200 and the end line set to both CR and LF, per the RYLR998 documentation; see:
https://reyax.com/products/RYLR998
Scroll down to “AT COMMAND MANUAL”.
The command “AT+MODE?” returned “+MODE=0”, which is consistent with the manufacturer’s documentation. The command “AT+SEND=1,5,HELLO” sent out this data, but the transmission was too quick to measure current draw on the ammeter. However, the ammeter did respond briefly, indicating that the current draw went way up when transmitting, consistent with the manufacturer’s data sheet.
The command “AT+MODE=1” returned “+OK/r/n” and the module powered down to 8.5 microamps. The command “AT+MODE=0” returned “+OK/r/n” and the module powered back up to 17.5 milliamps.
The command “AT+MODE=1” returned “+OK/r/n” and the module powered down to 8.5 microamps. The command “AT+SEND=1,5,HELLO” appeared to power the module back up and send out the message, but it returned “+MODE=0/r/n” in lieu of “+OK/r/n”.
These tests verify that the module powers up and powers down according to the manufacturer’s data.

Communication Testing with Power Switching.

These tests were performed to confirm the timing operation of powering up the LoRa module, sending out a short message, and then powering the module back down. It was performed in order to confirm that a command is complete and a new command to the module can be sent immediately after “+OK/r/n” is returned from the module to the microcontroller. In particular, we confirmed that we can power the LoRa module down immediately upon receiving “+OK/r/n” after a SEND command and that the LoRa transmission will be complete.
Two LoRa modules were pre-configured, as described below.

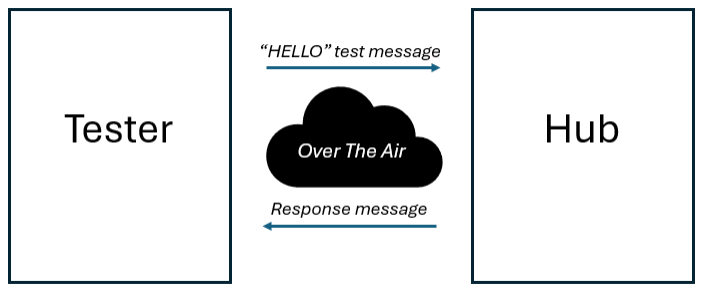
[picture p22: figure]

Figure 2. Range Testing Architecture.

The module designated for the “tester” was connected to a Particle Photon microcontroller that was programmed to send a short test message via the LoRa module whenever an onboard pushbutton was pressed. Specifically, the LoRa module is powered up, the test message is sent to the hub, and the LoRa module is powered down. The response message from the module (“+OK/r/n”) must always be received before a new command can be issued, but no further delays are required. Powering the LoRa module down was confirmed with an ammeter on the 3.3 volt power to the module.
The module designated for the “hub” is the same as the hub used for range testing. The hub’s LoRa module was connected to a Particle Photon microcontroller that was programmed to wait for receipt of a test message from the “tester” and, if a valid message was received, to transmit back a response message to the “tester” via its own LoRa module. The received message is also sent to a host computer via the Photon’s USB serial port and the message is displayed on a serial monitor for confirmation that the full and correct message was received.
Both the “tester” and the “Hub” were powered via USB on the Photon.
EQUIPMENT DESCIPTION.

Parts.

The following parts were used for these tests:

- 2 ea. RYLR998 LoRa Modem Modules. https://www.amazon.com/dp/B099RM1XMG?psc=1&ref=ppx_yo2ov_dt_b_product_details (https://www.amazon.com/dp/B099RM1XMG?psc=1&ref=ppx_yo2ov_dt_b_product_details)
- 1 ea. USB-Serial (“FTDI”) Module. https://www.amazon.com/dp/B00LODGRV8?psc=1&ref=ppx_yo2ov_dt_b_product_details (https://www.amazon.com/dp/B00LODGRV8?psc=1&ref=ppx_yo2ov_dt_b_product_details)
- 2 ea. Particle Photon modules. https://www.particle.io/. NOTE: The Photon is currently out of production; the Photon 2 may be used instead. The WiFi and BLE capabilities of the Photon/Photon 2 are not used for these tests and any 3.3 volt/USB powered Arduino board may be used.
- 1 ea. Breadboard compatible pushbutton switch.
- 2 ea. Solderless breadboard and male-male jumper wires.
- 1 ea. USB battery power supply.
- 1 ea. Multimeter.
Construction.

The figure below shows the “tester”:

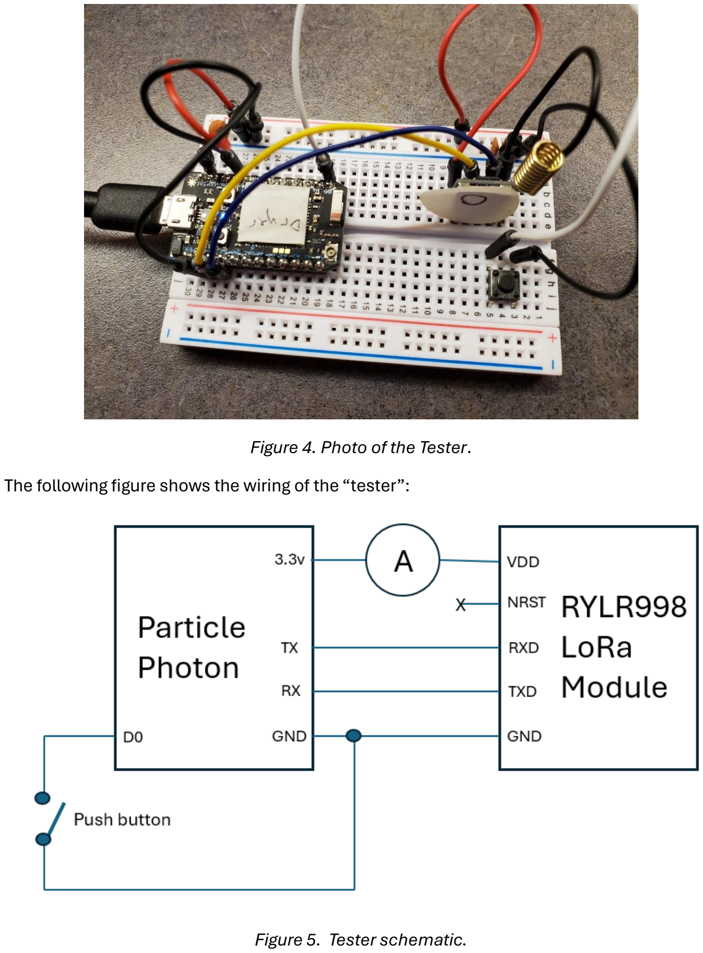
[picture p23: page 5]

Figure 4. Photo of the Tester. The following figure shows the wiring of the “tester”:

Figure 5. Tester schematic.

The Photon is powered through its onboard USB port. The Photon’s 3.3 volt output (from its on-board regulator) is used to power the LoRa module though an ammeter (multimeter on the DC amps setting). The Photon’s TX pin (Serial1 port) is connected to the LoRa module’s RXD pin and visa-vera. The LoRa module’s NRST (reset) pin is not connected.
The pushbutton switch has one end connected to the Photon D0 pin and the other end connected to ground.
The figure below shows the “hub”:

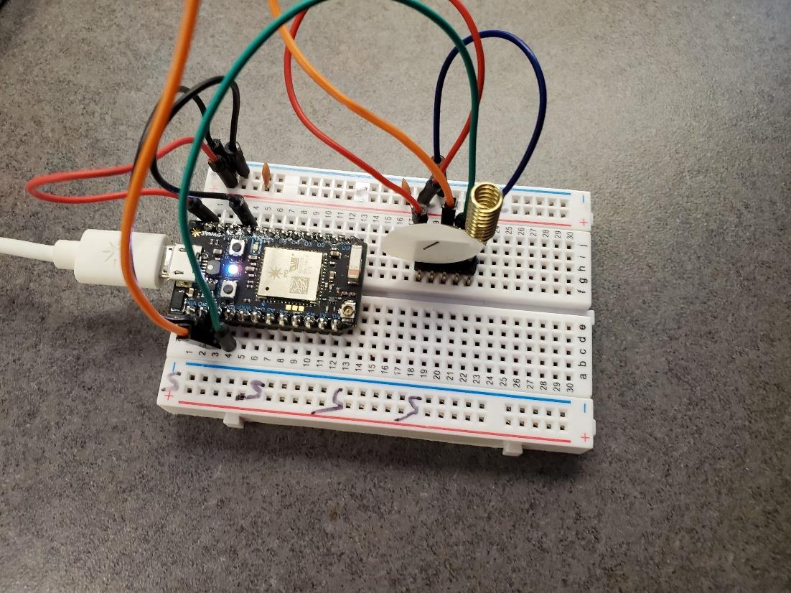
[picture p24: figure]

Figure 6. Photo of the Hub. The following figure shows the wiring of the “hub”:

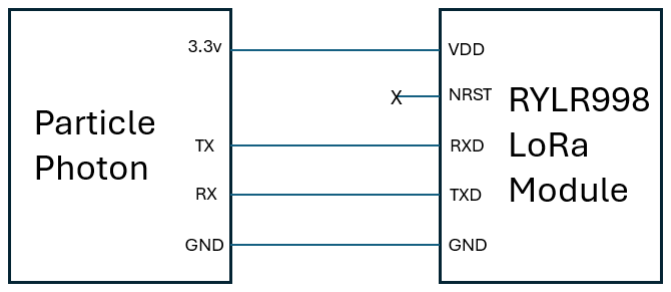
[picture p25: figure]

Figure 7. Hub Schematic.
The “hub” is the same (hardware and software) as for LoRa Range Testing.
SETUP AND CONFIGURATION.

The “hub” and “tester” software does not configure the LoRa modules. The modules must be set up using the USB-Serial module (“FTDI” module) and a PC running a terminal program. The terminal program used for these tests was the Arduino serial monitor; however, any terminal program will work.
The LoRa modules come “out-of-the-box” with a number of default settings. In general, the default settings were used for these tests. However, the module number and the network number were changed. The official documentation of the module AT command set can be found at:
https://reyax.com/products/RYLR998
Scroll down to “AT COMMAND MANUAL”.
The default baud rate for these LoRa modules is 115200 baud, and the default end-of-line is CR and LF (“/r/n”). In order to communicate with these modules using a terminal program on a PC, this baud rate and end-of-line settings must be used. Here are the settings used for these tests:

## Hub:

- Baud rate: 115200 (default)
- Mode: 0 (default)

- Band (for USA): 915 MHz (default)
- Network ID: 3
- Address: 0 (default)
- Parameters: (all default)
- Spreading factor: 9
- Bandwidth: 125 KHz
- Coding Rate: 1
- Preamble: 12

## Tester:

- Baud rate: 115200 (default)
- Mode: 0 (default)
- Band (for USA): 915 MHz (default)
- Network ID: 3
- Address: 1
- Parameters: (all default)
- Spreading factor: 9
- Bandwidth: 125 KHz
- Coding Rate: 1
- Preamble: 12
Note that only the network ID and the module address were changed from the defaults. The two modules must be set to different addresses, but they must both have the same network ID.
SOFTWARE DESCRIPTION.

The software (firmware) source code for the “hub” and “tester” is included in this repository. The software is well commented; hence only a brief description is given here.
Tester Software.

The “tester” software must operate independently of whether the “tester” can connect to WiFi. In order to use a Particle Photon, the “semi-automatic” system mode must be declared up front.

The “tester” software sets up things in setup(), including setting up D0 as INPUT_PULLUP and setting the Serial1 (LoRa module) baud rate for 115200. In loop(), the software tests for depression of the pushbutton. When the button is depressed, it :
1. Powers up the LoRa module (“AT+MODE=0”), and waits for the full OK message to be received.
2. Sends the “hello” message to the hub (“AT+SEND=1,5,HELLO”), and waits for the full OK message to be received.
3. Powers down the LoRa module (“AT+MODE=1”), and waits for the full OK message to be received.
4. Waits for the push button to be released, and then waits for it to again be depressed. NOTE: The “+OK” must be received from the LoRa module before a new command can be sent (according to the manufacturer’s documentation). We are not explicitly testing for “+OK/r/n”) because what would we do if we got an error instead? Rather, we simply wait for a complete response message from the LoRa module after each command is sent. A complete response is assured by setting Serial1.setTimeout(10); in setup(). With this setting, Serial1.readString(); keeps reading characters from the serial buffer and adding them to the received data string until there are no more characters for 10 milliseconds. This timeout should be more then long enough to assure that a complete response string has been received, event at a lower serial baud rate e.g. 9600 baud).

Hub Software.

The “hub” software is the same as for LoRa range testing. The “hub” software sets up things in setup(), setting the Serial1 (LoRa module) baud rate for 115200, and the Serial (USB) baud rate to 9600 (for debugging using a terminal program), and then enters loop(). In loop(), the software tests for data in the Serial1 receive buffer. If there is data in the buffer, is it read out and appended to a string variable to assemble the received message. Each time that data is added to the received message string variable, it is tested to see if the message is the test message from the “tester” (“HELLO”). If the test message has been received, the “hub” prints the received message to the USB serial port, sends out the response message back to the “tester”, and clears out the message string variable for another test.

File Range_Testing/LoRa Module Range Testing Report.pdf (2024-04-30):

# LoRa Module Range Testing Report

By: Bob Glicksman; 4/30/24
OVERVIEW.

This document describes the range tests performed on the RYLR998 LoRa modules (https://reyax.com/products/RYLR998). These tests were performed in order to verify that these modules meet the range requirements of the IVGM project. Specifically, these tests verified that the modules can successfully communicate between a mailbox located up to 100 feet in front of a house and a hub located just inside of the house.

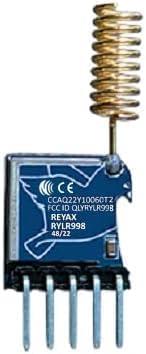
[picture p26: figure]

Figure 1. RYLR998 LoRa Modem Module.
RESULTS.

The RYLR998 LoRa modules easily met the project requirements; in fact, substantially exceeding them. Two range tests were performed:

1. The “hub” was placed in the back of the house. The “tester” was able to communicate with the hub at a distance of over 700 feet outside of the front of the house. Communication was successful over 700 feet of line of sight free air plus about 50 feet through many walls of the house.
2. The “hub” was placed in the front of the house, with only the front wall between the hub and outside free air. The “tester” was able to communicate with the hub at a distance of over 1000 feet outside of the front of the house. Communication was successful over 1000 feet of line of sight free air plus about 2 feet through the front wall of the house. Communication was lost when line of sight to the house was compromised by the street environment. It is possible that communication over longer distances would have been successful if there was a longer line of sight to the house in the test environment.

Additional, free air – line of sight tests may be conducted in the future.
TESTING METHODOLOGY.

Two LoRa modules were pre-configured, as described below.


Figure 2. Range Testing Architecture.

The module designated for the “tester” was connected to a Particle Photon microcontroller that was programmed to send a short test message via the LoRa module whenever an onboard pushbutton was pressed. The module designated for the “hub” was connected to a Particle Photon microcontroller that was programmed to wait for receipt of a test message from the “tester” and, if a valid message was received, to transmit back a response message to the “tester” via its own LoRa module. After sending out the test message, the “tester” waits three seconds and then reads out its LoRa module received response. If a valid response was received, the Photon microcontroller on the “tester” flashes its D7 LED three times. If no valid response message was received, the “test” flashes its D7 LED once. These tests were not performed at low power. The “hub” was powered from the AC mains by a USB power supply. Since the tester had to be operated outside, on the street, it was powered by a camping battery/inverter power source; see the figure below.

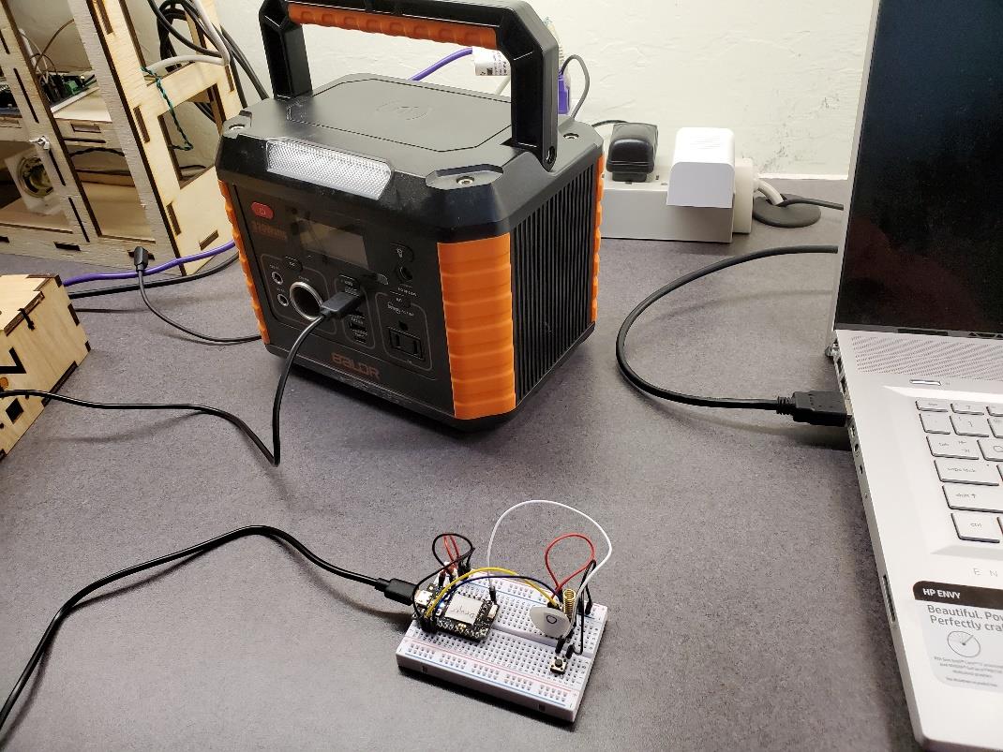
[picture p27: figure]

Figure 3. “Tester” and its portable power source. The “hub” was stationary while the “tester” was manually transported to various locations on the street at increasing distances from the house (but trying to keep line of sight to the house). At periodic intervals, the button on the “tester” was pressed and the D7 LED observed after the three second delay. Three flashes indicated successful communication while one flash indicated loss of communication. The point of loss of communication was noted on Google Maps and the Google Map scale was used to determine the distance from the house.
EQUIPMENT DESCIPTION.

Parts.

The following parts were used for these tests:

- 2 ea. RYLR998 LoRa Modem Modules. https://www.amazon.com/dp/B099RM1XMG?psc=1&ref=ppx_yo2ov_dt_b_product_details (https://www.amazon.com/dp/B099RM1XMG?psc=1&ref=ppx_yo2ov_dt_b_product_details)
- 1 ea. USB-Serial (“FTDI”) Module. https://www.amazon.com/dp/B00LODGRV8?psc=1&ref=ppx_yo2ov_dt_b_product_details (https://www.amazon.com/dp/B00LODGRV8?psc=1&ref=ppx_yo2ov_dt_b_product_details)

- 2 ea. Particle Photon modules. https://www.particle.io/. NOTE: The Photon is currently out of production; the Photon 2 may be used instead. The WiFi and BLE capabilities of the Photon/Photon 2 are not used for these tests and any 3.3 volt/USB powered Arduino board may be used.
- 1 ea. Breadboard compatible pushbutton switch.
- 2 ea. Solderless breadboard and male-male jumper wires.
- 1 ea. USB battery power supply.
Construction.

The figure below shows the “tester”:

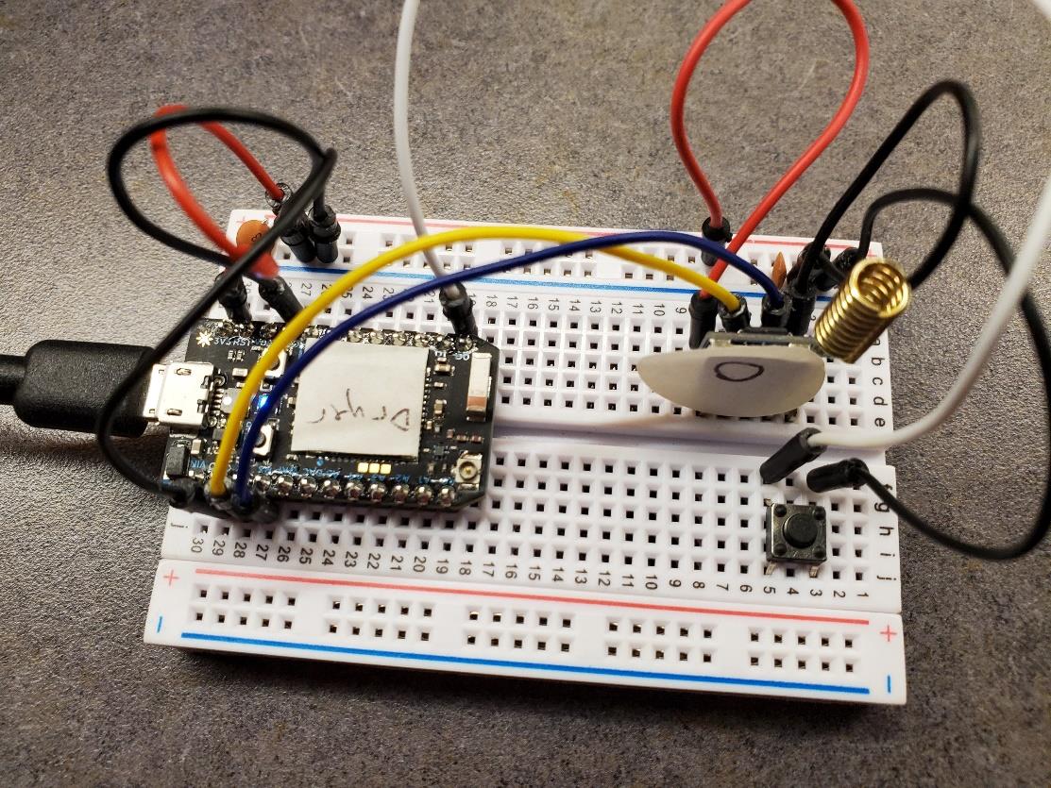
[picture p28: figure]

Figure 4. Photo of the Tester. The following figure shows the wiring of the “tester”:

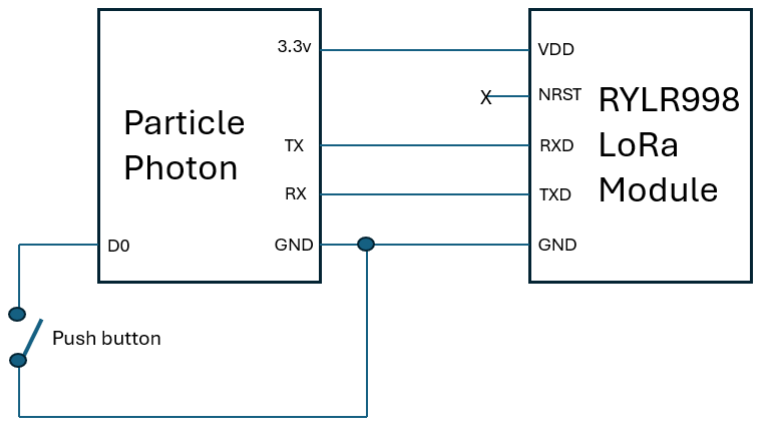
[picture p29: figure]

Figure 5. Tester schematic. The Photon is powered through its onboard USB port. The Photon’s 3.3 volt output (from its on-board regulator) is used to power the LoRa module. The Photon’s TX pin (Serial1 port) is connected to the LoRa module’s RXD pin and visa-vera. The LoRa module’s NRST (reset) pin is not connected.
The pushbutton switch has one end connected to the Photon D0 pin and the other end connected to ground.
The figure below shows the “hub”:

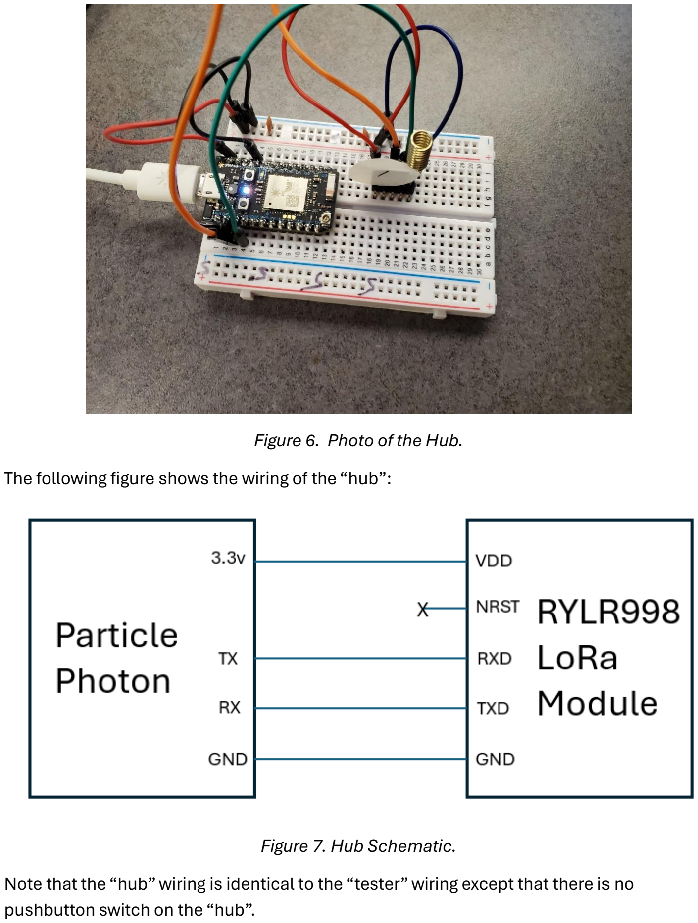
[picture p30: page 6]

Figure 6. Photo of the Hub. The following figure shows the wiring of the “hub”:

Figure 7. Hub Schematic.
Note that the “hub” wiring is identical to the “tester” wiring except that there is no pushbutton switch on the “hub”.

SETUP AND CONFIGURATION.

The “hub” and “tester” software does not configure the LoRa modules. The modules must be set up using the USB-Serial module (“FTDI” module) and a PC running a terminal program. The terminal program used for these tests was the Arduino serial monitor; however, any terminal program will work.
The LoRa modules come “out-of-the-box” with a number of default settings. In general, the default settings were used for these tests. However, the module number and the network number were changed. The official documentation of the module AT command set can be found at:
https://reyax.com/products/RYLR998
Scroll down to “AT COMMAND MANUAL”.
The default baud rate for these LoRa modules is 115200 baud, and the default end-of-line is CR and LF. In order to communicate with these modules using a terminal program on a PC, this baud rate and end-of-line settings must be used. Here are the settings used for these tests:

## Hub:

- Baud rate: 115200 (default)
- Mode: 0 (default)
- Band (for USA): 915 MHz (default)
- Network ID: 3
- Address: 0 (default)
- Parameters: (all default)
- Spreading factor: 9
- Bandwidth: 125 KHz
- Coding Rate: 1
- Preamble: 12

## Tester:

- Baud rate: 115200 (default)
- Mode: 0 (default)
- Band (for USA): 915 MHz (default)
- Network ID: 3

- Address: 1
- Parameters: (all default)
- Spreading factor: 9
- Bandwidth: 125 KHz
- Coding Rate: 1
- Preamble: 12
Note that only the network ID and the module address were changed from the defaults. The two modules must be set to different addresses, but they must both have the same network ID.
SOFTWARE DESCRIPTION.

The software (firmware) source code for the “hub” and “tester” is included in this repository. The software is well commented; hence only a brief description is given here.
Tester Software.

The “tester” software must operate independently of whether the “tester” can connect to WiFi. In order to use a Particle Photon, the “semi-automatic” system mode must be declared up front.
The “tester” software sets up things in setup(), including setting up D0 as INPUT_PULLUP, setting the Serial1 (LoRa module) baud rate for 115200, and the Serial (USB) baud rate to 9600 (for debugging using a terminal program), and then enters loop(). In loop(), the software tests for depression of the pushbutton. When the button is depressed, it sends out the “HELLO” message to the hub and sets a flag to expect a response from the hub. The code then waits for 3 seconds, after which the received data is read. The received data contains both the local response from the module’s sending command (“+OK” CR/LF) and any received response message (after 3 seconds). The code tests for “+RCV” in the message buffer to detect receipt of a response message. If a response message was received within 3 seconds, the D7 LED is flashed three times; otherwise it is flashed once. The code then waits for the pushbutton to be released, after which loop() repeats, waiting for the button to be pressed once again.

Hub Software.

The “hub” software sets up things in setup(), setting the Serial1 (LoRa module) baud rate for 115200, and the Serial (USB) baud rate to 9600 (for debugging using a terminal program), and then enters loop(). In loop(), the software tests for data in the Serial1 receive buffer. If there is data in the buffer, is it read out and appended to a string variable to assemble the received message. Each time that data is added to the received message string variable, it is tested to see if the message is the test message from the “tester” (“HELLO”). If the test message has been received, the “hub” sends out the response message back to the “tester” and clears out the message string variable for another test.
HOW THE LORA MODULES COMMUNICATE.

The LoRa modules communicate using “AT” commands, as specified in the manufacturer's “AT COMMAND MANUAL”, which can be found at: https://reyax.com/products/RYLR998 Here is a capture of communication between the “tester” and the “hub”.


Figure 8. screen captures of communication. Referring to figure 8, “COM 6” is from the “tester” and “COM 4” is from the “hub”.
The “tester” sends out its “HELLO” message after the button is pushed. The command to the LoRa module is:
“AT+SEND=1,5,HELLO”
All LoRa modules commands begin with “AT+”. The “SEND” command is to transmit data. The “1” parameter is the address of the intended recipient (in this case, 1 is the address set on the “hub” LoRa module). The next parameter is the size of the message. It is “5” because “HELLO” has 5 characters.
The “hub” receives this message, as shown in “COM 4”:
“+RCV=0,5,HELLO,-37,11”

“+RCV=” is what the LoRa module uses to designate a received message. “0” is the address of the module that sent the message (in this case, “0” is the address of the “tester”). “5”is the length of the received message and “HELLO” is the received message itself. The remaining two parameters are RSSI and SNR – these relate to the quality of the received signal (see the AT COMMAND MANUAL for details).
Referring to “COM 4”, the “hub”, having received a correct test message, sends out its response message (message data: “TEST”). The “hub” then receives “+OK” – this is a local response from the local LoRa module to the SEND command.

Referring back to “COM 6”:
The received data (after three seconds) contains the following:
“+OK CR/LF +RCV=1,4,TEST,-26,10 CR/LF”
This response is a little complicated. The first part: “+OK CR/LF” is the local response from the local LoRa module to the original “HELLO” message SEND command. This part means that the command was accepted by the LoRa module OK.
(p.s. – it is currently unclear whether +OK means that the AT string was formatted properly, that the send command was sent to the LoRa chip OK, or whether the LoRa chip transmitted the command in a proper LoRa packet, or even that the message was acknowledged by the receiver. More testing and investigation needs to be done here).
The remainder of the message string is the message data received from the “hub”: “+RCV=” designates that this is a received message.
“1” is the address of the sender of the message (the “hub”, in this case). “4” is the length (in bytes) if the message (length of “TEST”).
“TEST” is the message itself.
The remaining two parameters are RSSI and SNR – these relate to the quality of the received signal (see the AT COMMAND MANUAL for details).
Figure 8 shows two sets of test message send, receive and respond.

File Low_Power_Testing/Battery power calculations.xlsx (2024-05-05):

Number of sensor activations per day: | 3 | ea | mailman + me + one other
Battery capacity | 1500 | ma-hr | Energizer 123
Active LoRa power - transmitting | 140 | ma | per data sheet
Active LoRa power - receiving/waiting | 17.5 | ma | per data sheet
Quiescent LoRa power | 0.01 | ma | 10 microamps, per data sheet
Actvice ATtiny85 power | 2 | ma | per data sheet
Sleep (Quiescent) ATtiny85 power | 0.002 | ma | 2 microamp, data sheet
Quiescent switch pullup power | 0.003 | ma | 3 microamp - calculated
Quiescent reset pulse logic power | 0.04 | ma | 40 microamp max, per datasheet
Active sensor transmission time: | 165 | ms | from https://www.thethingsnetwork.org/airtime-calculator
Overhead time (sensor powered up but not X-mitting):
power up message + OK response + 10 ms timeout | 26 | ms | assume about 1 ms per chacrater (9600 baud)
transmitted message + OK response + 10 ms timeout | 34 | ms | assume about 1 ms per chacrater (9600 baud)
power down message + OK response + 10 ms timeout | 26 | ms | assume about 1 ms per chacrater (9600 baud)
add a few misc milliseconds | 10 | ms
Calculate Quiescent Current Draw: | 0.055 | ma | reset pulse gen + pullup + Attiny + LoRa quiescnet current
Calculate Quiescent Power: | 0.055 | ma-hr | quiescent power draw is continuous
Calculate Active Power Draw:
LoRa transmitting power when transmitting: | 23100 | ma-ms
LoRa transmitting power when transmitting: | 0.006416666667 | ma-hr
Total of all LoRa transmission power per day : | 0.01925 | ma-hr / day
Total overhead time (receiving): | 96 | ms
LoRa current draw receiving mode: | 1680 | ma - ms
LoRa power draw receiving mode: | 0.0004666666667 | ma-hr
LoRa power draw receiving mode per day: | 0.0014 | ma-hr/day
Total active Attiny time: | 261 | ms
Attiny active power draw: | 522 | ma-ms
Attiny active power draw: | 0.000145 | ma-hr
Total Attiny power draw / day expressed in hours: | 0.000435 | ma-hr/day
Total active power draw per day: | 0.021085 | ma-hr/day
Total power draw per day: | 1.341085 | ma-hr/day | quiescent power drawn 24 hr/day plus active power draw/day
Total days battery life: | 1118.497336 | days of life
Total Years Battery Life: | 3.062278812 | YEARS | NOTE: most of this is quiescent power - not that sensitive to active power!

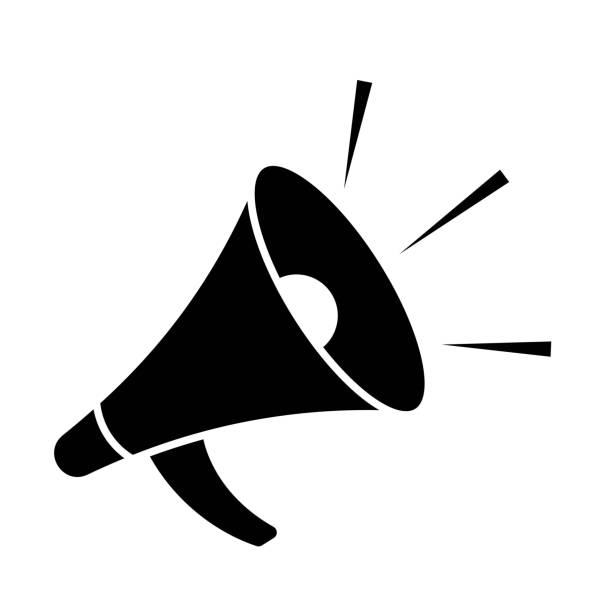
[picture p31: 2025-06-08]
Range_Testing/Range_Test_Hub/Clip Play App/Announcement.jpg

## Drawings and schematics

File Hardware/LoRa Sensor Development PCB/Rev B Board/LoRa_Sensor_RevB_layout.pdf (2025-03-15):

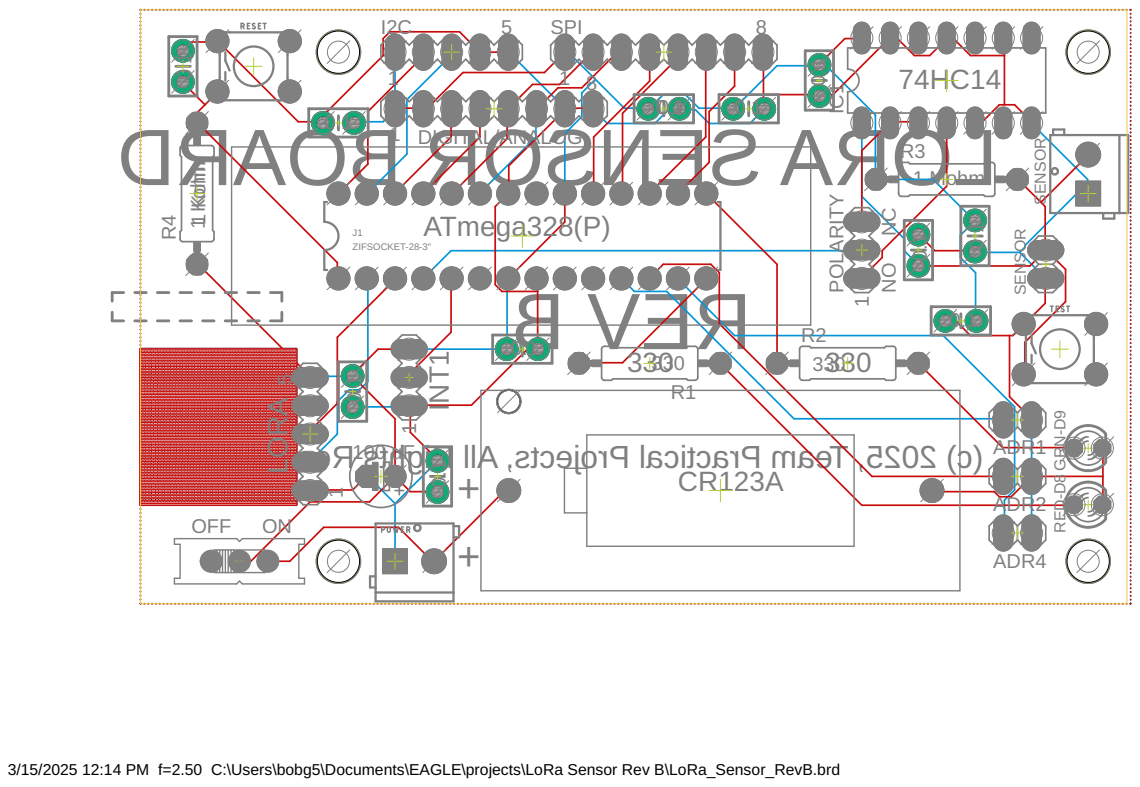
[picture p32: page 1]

3/15/2025 12:14 PM f=2.50 C:\Users\bobg5\Documents\EAGLE\projects\LoRa Sensor Rev B\LoRa_Sensor_RevB.brd

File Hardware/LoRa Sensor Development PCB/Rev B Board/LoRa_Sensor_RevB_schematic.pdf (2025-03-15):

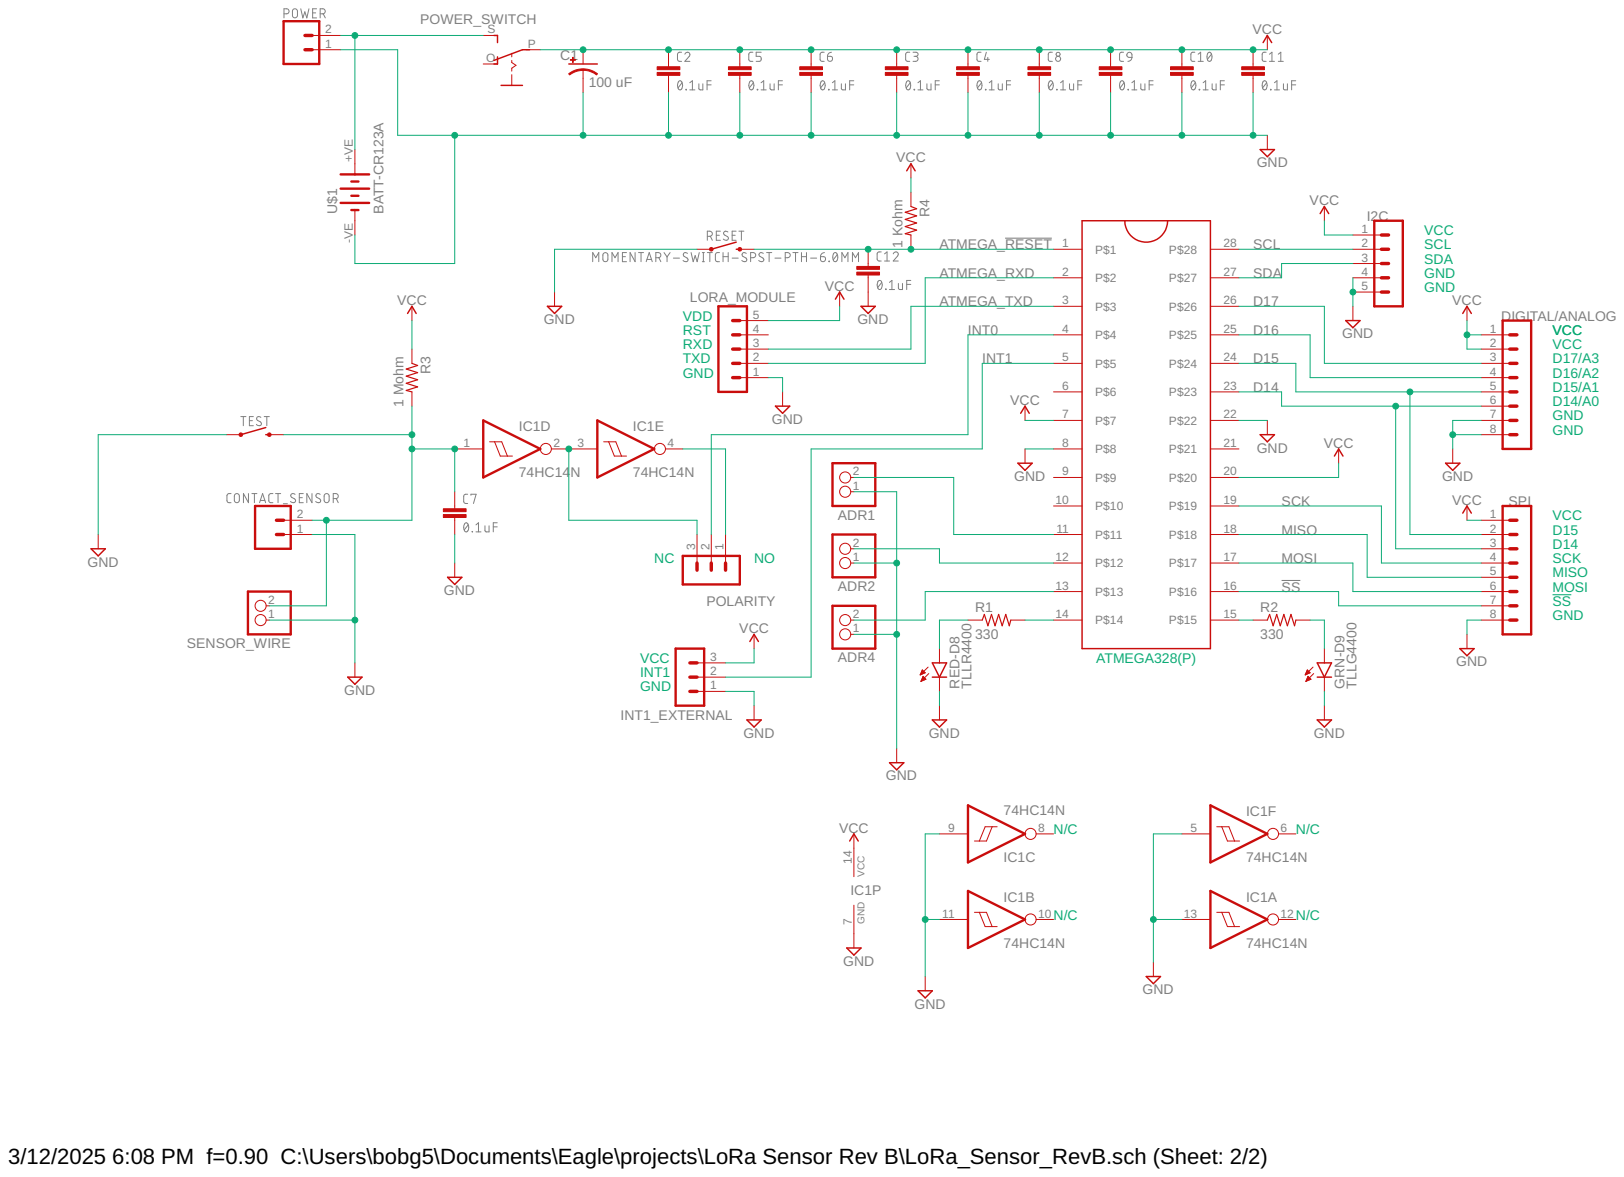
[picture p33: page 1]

GND
SCL SDA D17 D16 D15 D14 SCK MISO MOSI SS

VCC
SCL SDA GND GND

D15 D14 SCK MISO MOSI SS

3/12/2025 6:08 PM f=0.90 C:\Users\bobg5\Documents\Eagle\projects\LoRa Sensor Rev B\LoRa_Sensor_RevB.sch (Sheet: 2/2)

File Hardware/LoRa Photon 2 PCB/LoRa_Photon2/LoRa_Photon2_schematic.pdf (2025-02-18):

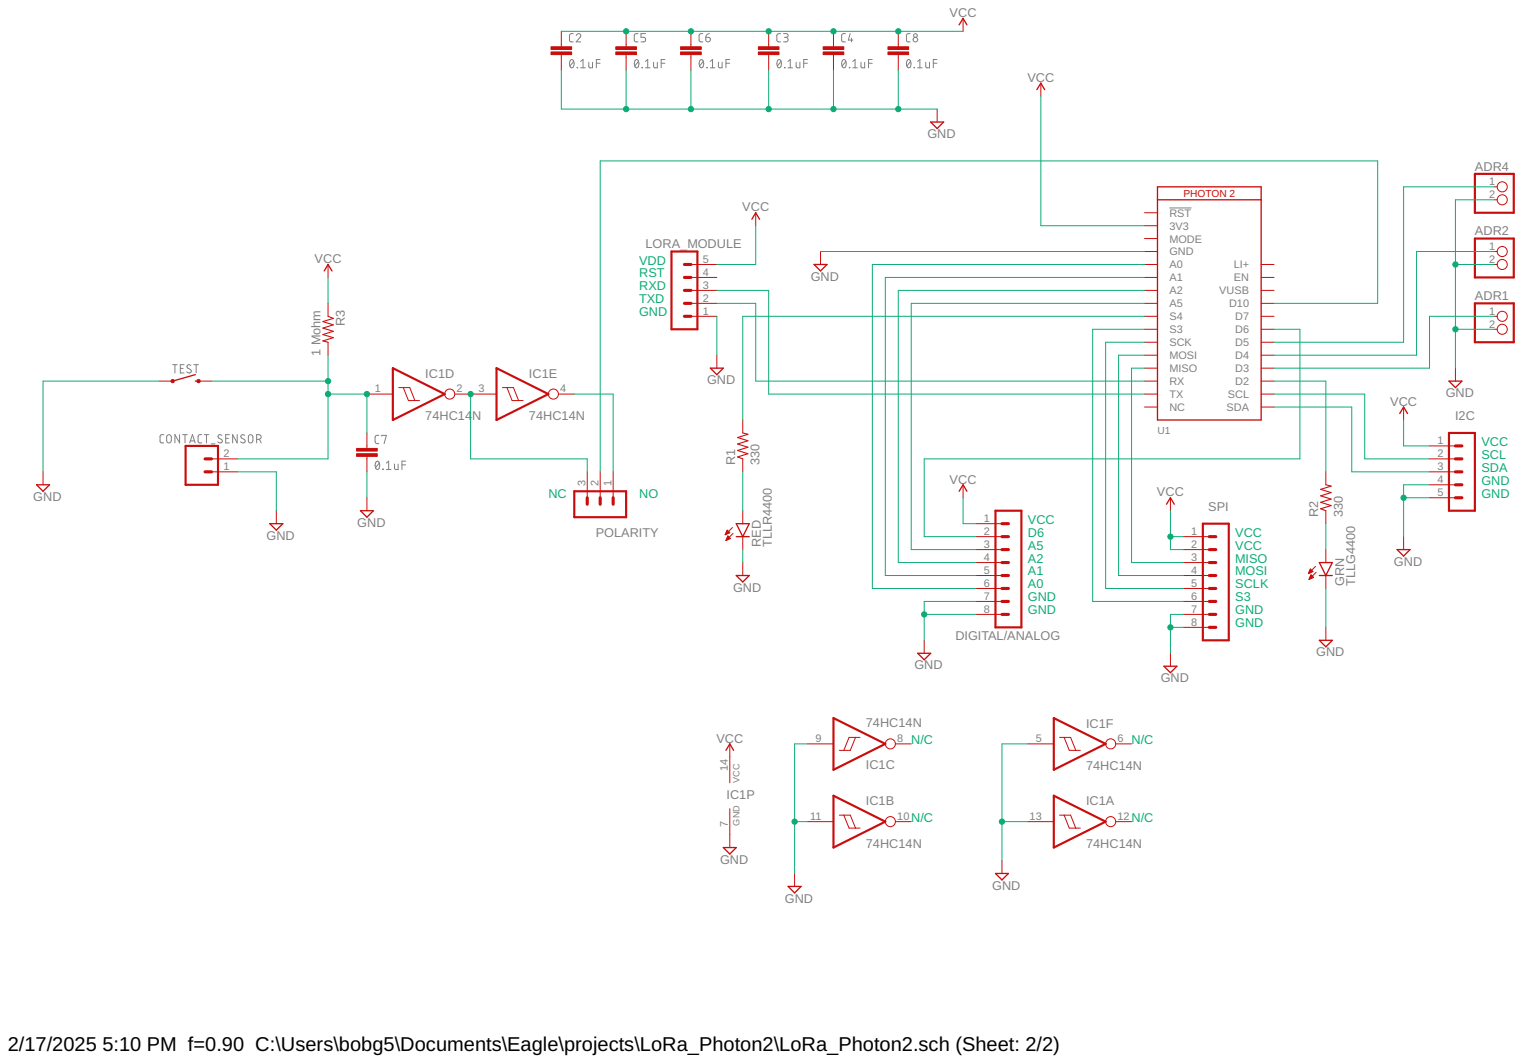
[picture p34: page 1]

VCC
SCL SDA GND GND

2/17/2025 5:10 PM f=0.90 C:\Users\bobg5\Documents\Eagle\projects\LoRa_Photon2\LoRa_Photon2.sch (Sheet: 2/2)

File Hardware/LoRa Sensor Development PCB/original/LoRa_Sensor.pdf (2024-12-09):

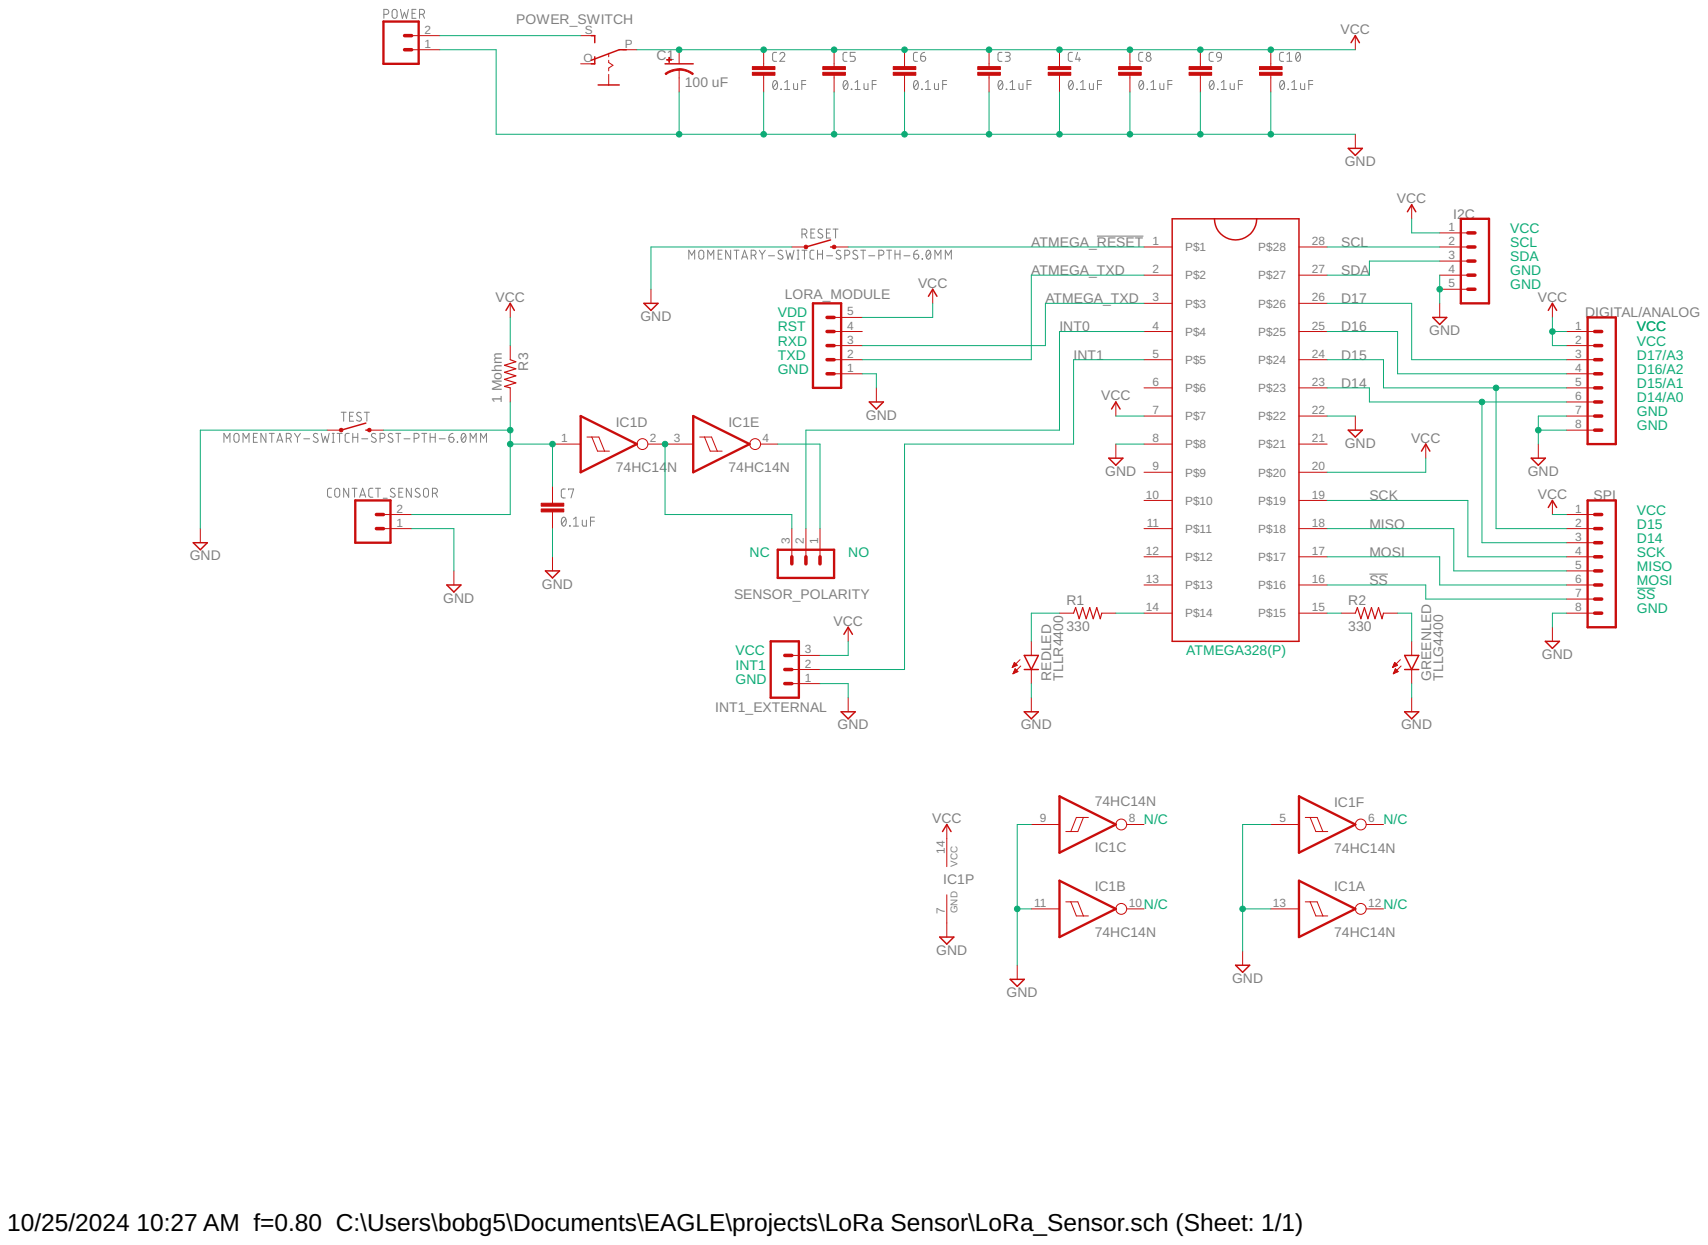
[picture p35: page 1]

VCC GND
SCL SDA D17 D16 D15 D14 SCK MISO MOSI SS

VCC
SCL SDA GND GND

D15 D14 SCK MISO MOSI SSGND

10/25/2024 10:27 AM f=0.80 C:\Users\bobg5\Documents\EAGLE\projects\LoRa Sensor\LoRa_Sensor.sch (Sheet: 1/1)

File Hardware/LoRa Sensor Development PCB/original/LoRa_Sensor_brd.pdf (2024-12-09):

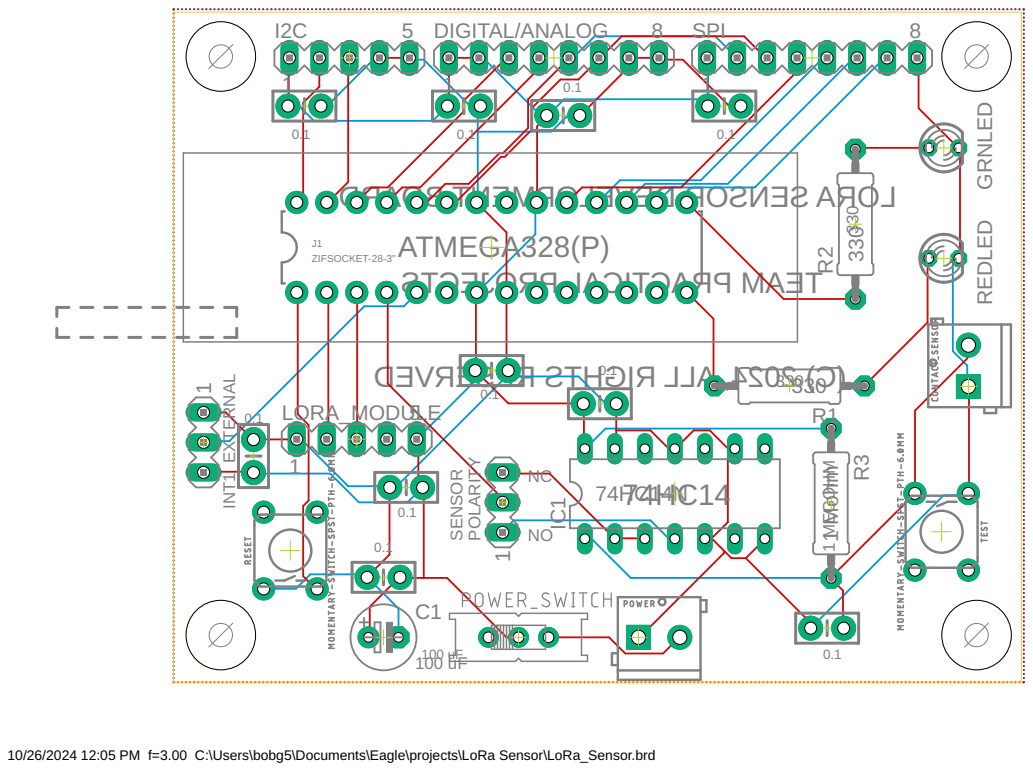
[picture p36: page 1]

10/26/2024 12:05 PM f=3.00 C:\Users\bobg5\Documents\Eagle\projects\LoRa Sensor\LoRa_Sensor.brd

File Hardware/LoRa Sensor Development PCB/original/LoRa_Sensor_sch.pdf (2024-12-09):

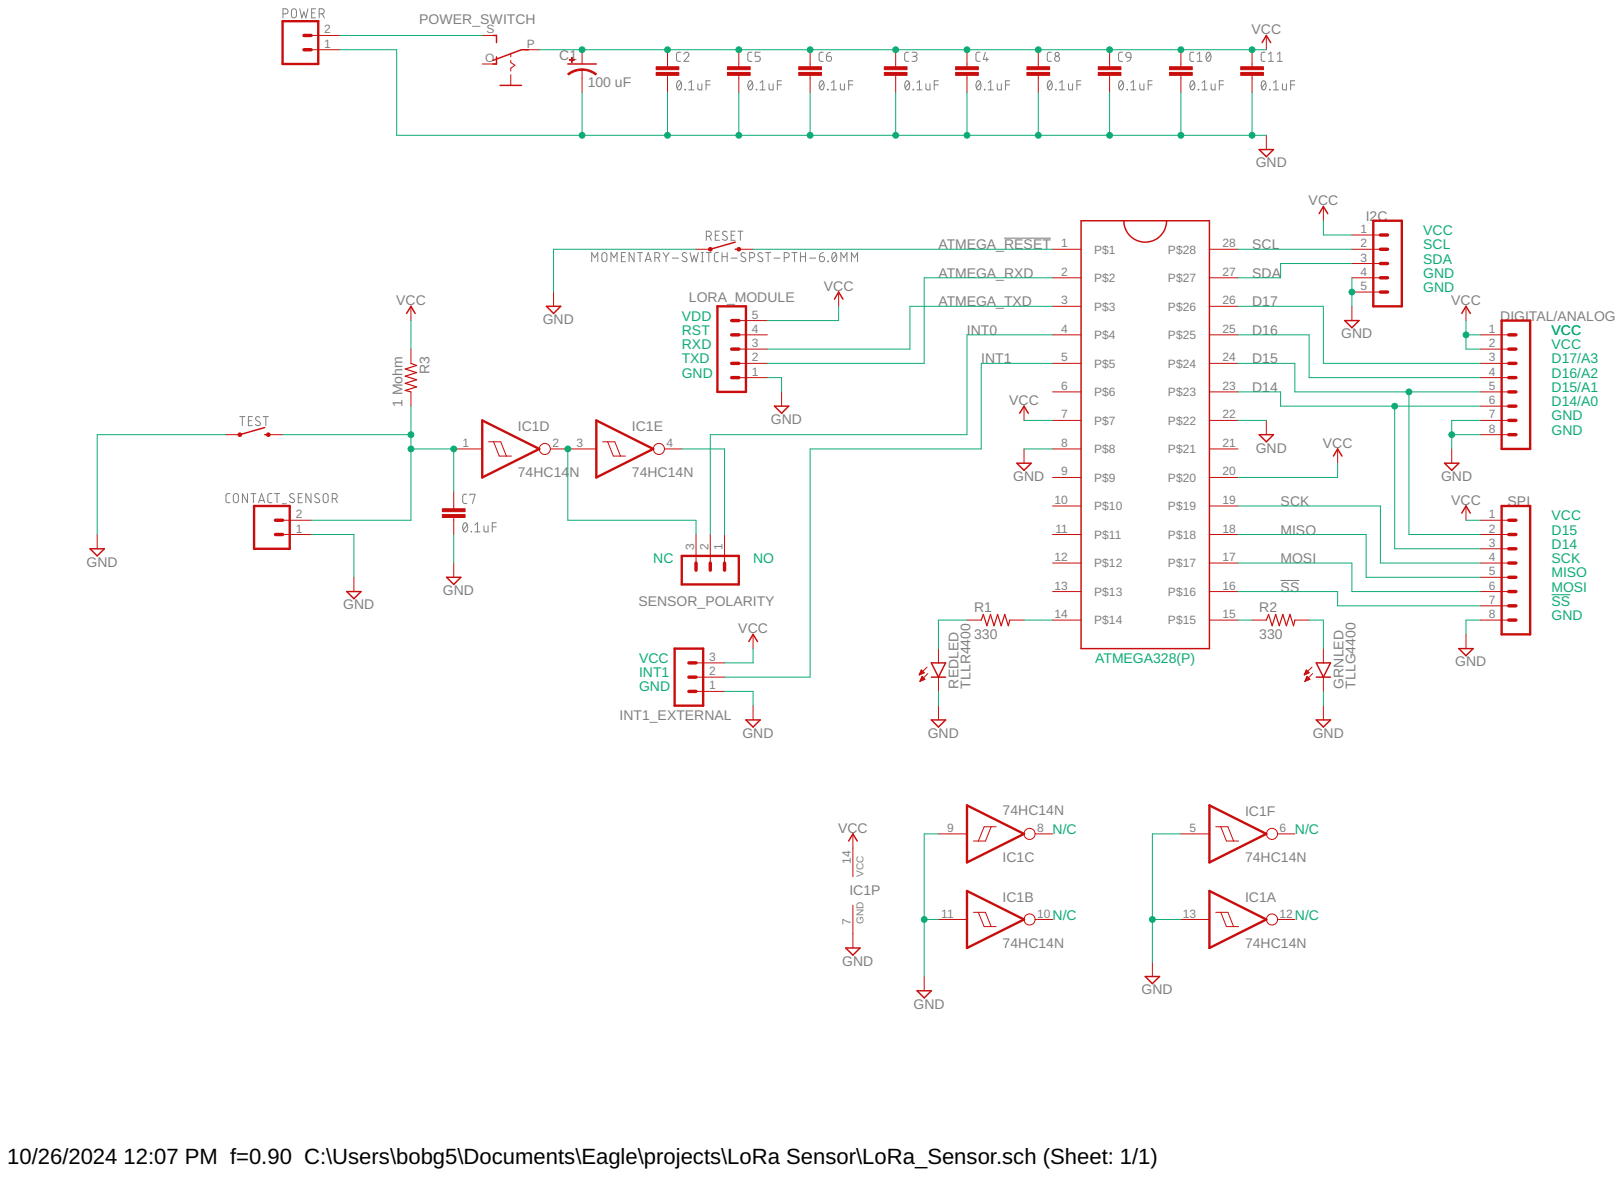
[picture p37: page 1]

GND
SCL SDA D17 D16 D15 D14 SCK MISO MOSI SS

VCC
SCL SDA GND GND

D15 D14 SCK MISO MOSI SS

10/26/2024 12:07 PM f=0.90 C:\Users\bobg5\Documents\Eagle\projects\LoRa Sensor\LoRa_Sensor.sch (Sheet: 1/1)

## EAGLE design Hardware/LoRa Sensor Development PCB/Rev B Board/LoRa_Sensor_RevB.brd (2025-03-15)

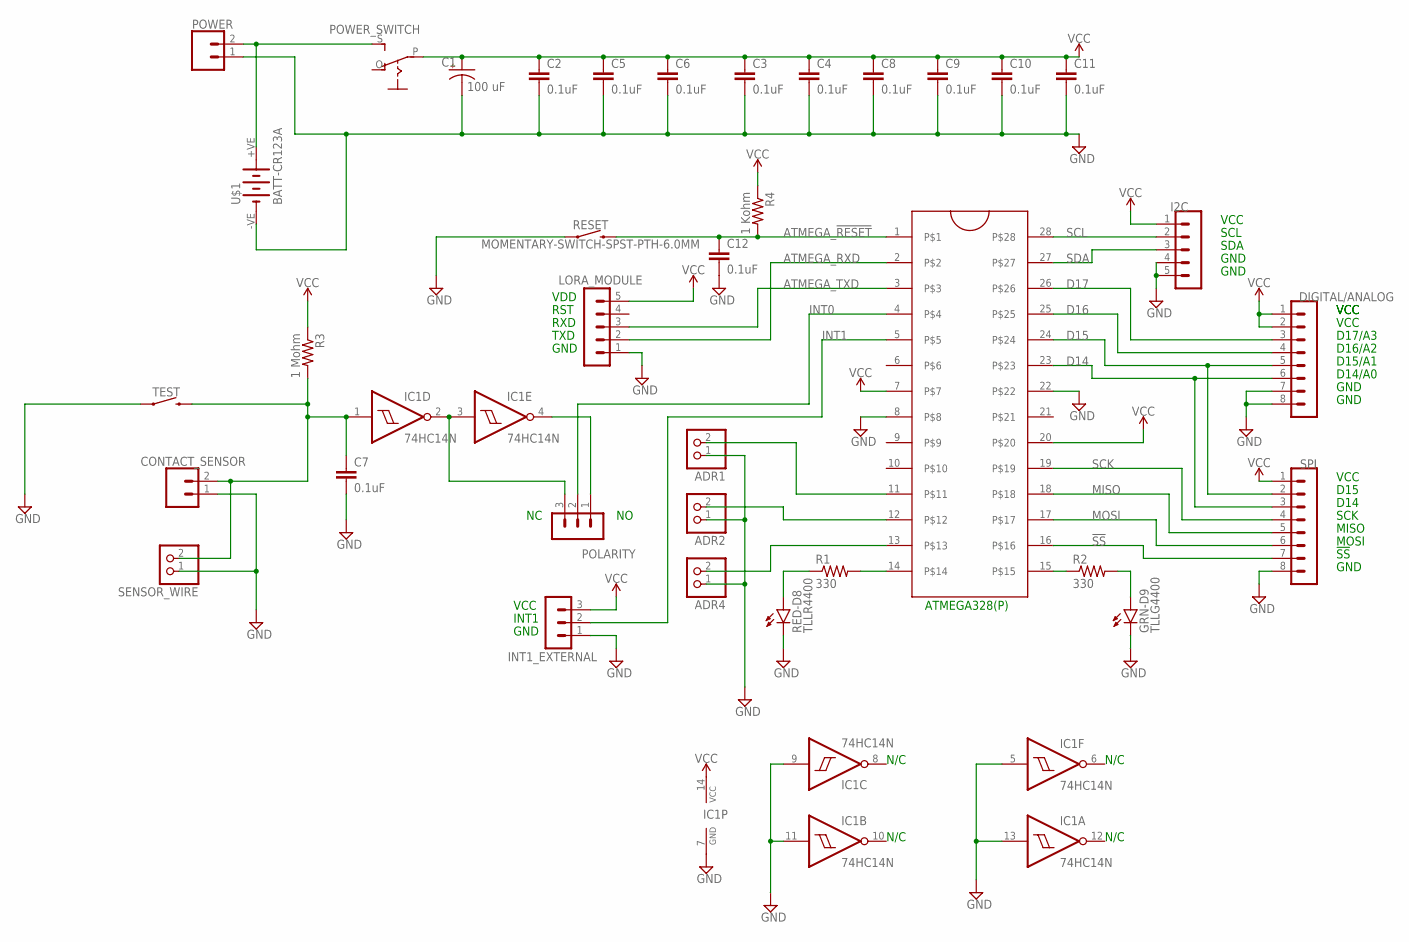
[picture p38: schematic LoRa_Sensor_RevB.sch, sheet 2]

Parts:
ADR1, ADR2, ADR4: PINHD-1X2; 1X02
C1: 100 uF; E2,5-6
C2, C3, C4, C5, C6, C7, C8, C9, C10, C11, C12: 0.1uF; CAP-PTH-SMALL-KIT
CONTACT_SENSOR: CONN_023.5MM; SCREWTERMINAL-3.5MM-2
DIGITAL/ANALOG: MA08-1
GRN-D9: TLLG4400; LED3MM
I2C: MA05-1
IC1: 74HC14N; DIL14
INT1_EXTERNAL: MA03-1
J1: ZIFSOCKET-28-3"; DIL28-3-ZIF_SOCKET
LORA_MODULE: MA05-1
POLARITY: MA03-1
POWER: CONN_023.5MM; SCREWTERMINAL-3.5MM-2
POWER_SWITCH: EG1218S; EG1218
R1, R2: 330; 0309/12
R3: 1 Mohm; 0309/12
R4: 1 Kohm; 0309/12
RED-D8: TLLR4400; LED3MM
RESET: MOMENTARY-SWITCH-SPST-PTH-6.0MM; TACTILE_SWITCH_PTH_6.0MM
SENSOR_WIRE: PINHD-1X2; 1X02
SPI: MA08-1
TEST: MOMENTARY-SWITCH-SPST-PTH-6.0MM; TACTILE_SWITCH_PTH_6.0MM
U$1: BATT-CR123A; KEYSTONE-2/3A

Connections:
!SS: J1.16, SPI.7
ATMEGA_!RESET: C12.1, J1.1, R4.2, RESET.3 (2)
ATMEGA_RXD: J1.2, LORA_MODULE.2
ATMEGA_TXD: J1.3, LORA_MODULE.3
D14: DIGITAL/ANALOG.6, J1.23, SPI.3
D15: DIGITAL/ANALOG.5, J1.24, SPI.2
D16: DIGITAL/ANALOG.4, J1.25
D17: DIGITAL/ANALOG.3, J1.26
GND: ADR1.1, ADR2.1, ADR4.1, C1.-, C2.2, C3.2, C4.2, C5.2, C6.2, C7.2, C8.2, C9.2, C10.2, C11.2, C12.2, CONTACT_SENSOR.1, DIGITAL/ANALOG.7, DIGITAL/ANALOG.8, GRN-D9.K (C), I2C.4, I2C.5, IC1.5 (I), IC1.7 (GND), IC1.9 (I), IC1.11 (I), IC1.13 (I), INT1_EXTERNAL.1, J1.8, J1.22, LORA_MODULE.1, POWER.1, RED-D8.K (C), RESET.1, SENSOR_WIRE.1, SPI.8, TEST.1, U$1.-VE (-)
INT0: J1.4, POLARITY.2
INT1: INT1_EXTERNAL.2, J1.5
MISO: J1.18, SPI.5
MOSI: J1.17, SPI.6
unnamed: C7.1, CONTACT_SENSOR.2, IC1.1 (I), R3.2, SENSOR_WIRE.2, TEST.3 (2)
unnamed: POWER.2, POWER_SWITCH.S, U$1.+VE (+)
unnamed: J1.15, R2.1
unnamed: GRN-D9.A, R2.2
unnamed: J1.14, R1.2
unnamed: R1.1, RED-D8.A
unnamed: ADR4.2, J1.13
unnamed: IC1.2 (O), IC1.3 (I), POLARITY.3
unnamed: IC1.4 (O), POLARITY.1
unnamed: ADR2.2, J1.12
unnamed: ADR1.2, J1.11
SCK: J1.19, SPI.4
SCL: I2C.2, J1.28
SDA: I2C.3, J1.27
VCC: C1.+, C2.1, C3.1, C4.1, C5.1, C6.1, C8.1, C9.1, C10.1, C11.1, DIGITAL/ANALOG.1, DIGITAL/ANALOG.2, I2C.1, IC1.14 (VCC), INT1_EXTERNAL.3, J1.7, J1.20, LORA_MODULE.5, POWER_SWITCH.P, R3.1, R4.1, SPI.1

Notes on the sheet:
GND
TXD
RXD
RST
VDD
N/C
ATMEGA328(P)
VCC
INT1
SCL
SDA
D16/A2
D15/A1
D14/A0
D17/A3
D15
D14
SCK
MISO
MOSI
!SS

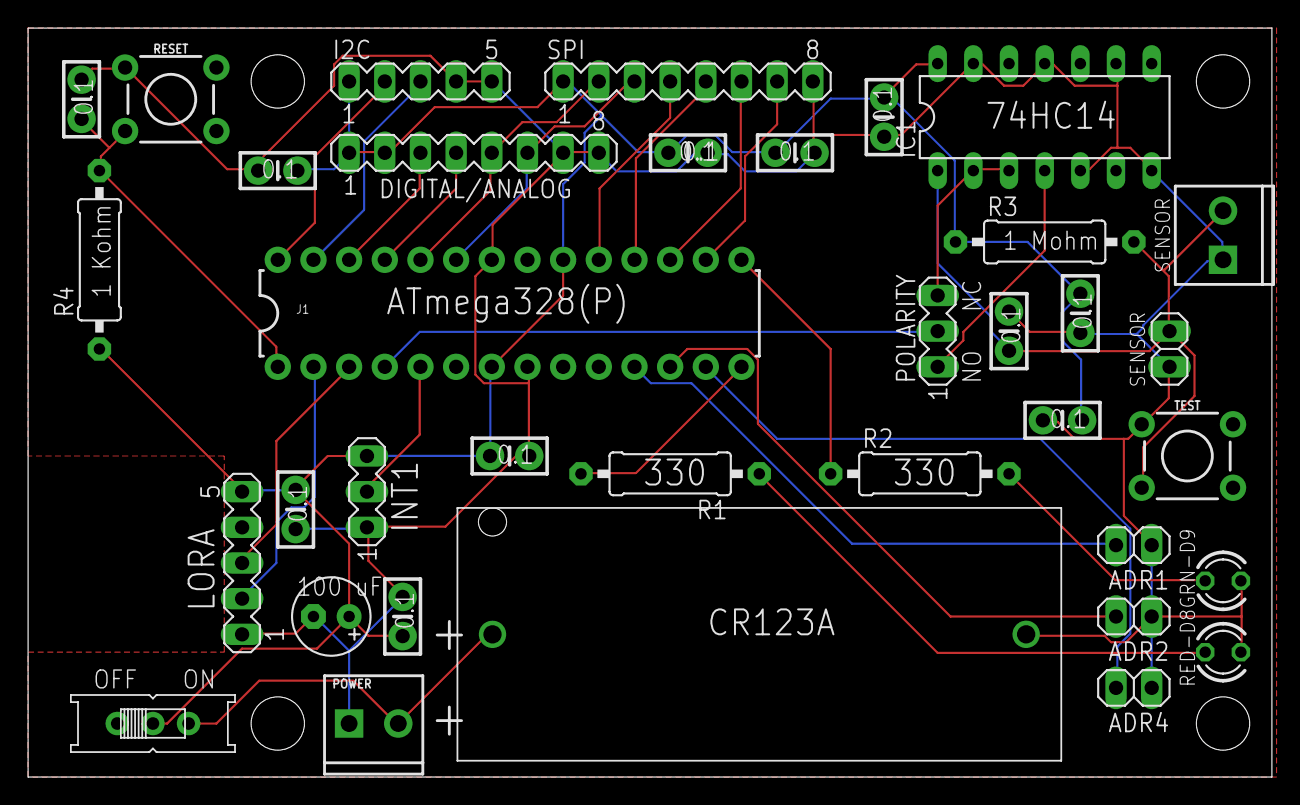
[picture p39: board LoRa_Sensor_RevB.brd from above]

Board: 2 copper layers, 88.6 x 53.3 mm, 36 parts (0 on the bottom side), 28 nets.

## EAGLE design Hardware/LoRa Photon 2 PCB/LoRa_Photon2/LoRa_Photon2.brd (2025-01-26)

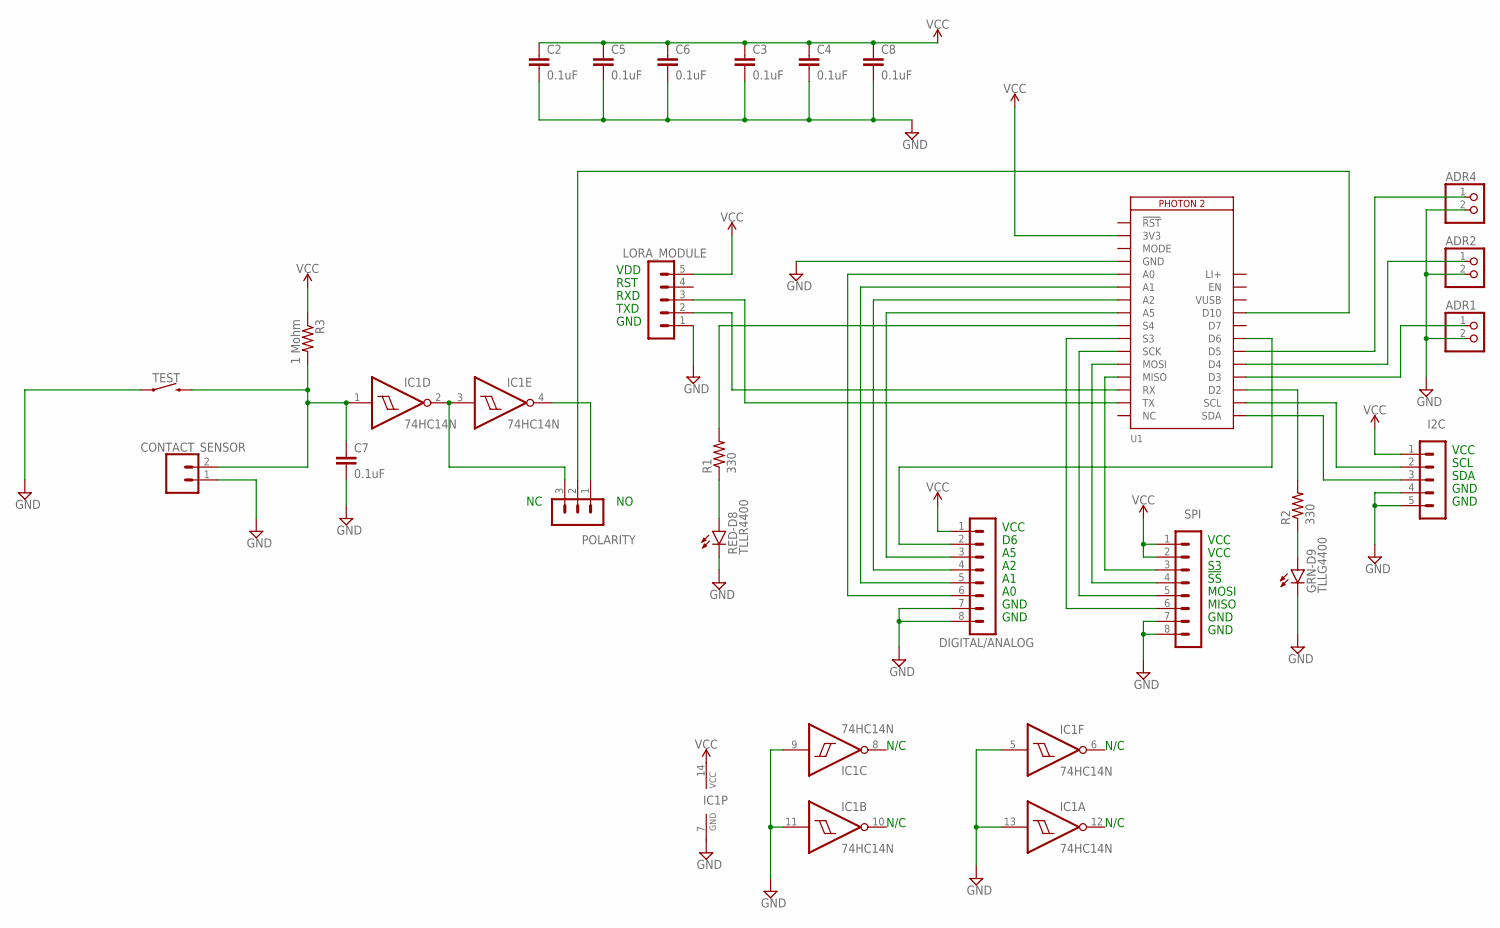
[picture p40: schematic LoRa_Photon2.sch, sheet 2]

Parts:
ADR1, ADR2, ADR4: PINHD-1X2; 1X02
C2, C3, C4, C5, C6, C7, C8: 0.1uF; CAP-PTH-SMALL-KIT
CONTACT_SENSOR: CONN_023.5MM; SCREWTERMINAL-3.5MM-2
DIGITAL/ANALOG: MA08-1
GRN-D9: TLLG4400; LED3MM
I2C: MA05-1
IC1: 74HC14N; DIL14
LORA_MODULE: MA05-1
POLARITY: MA03-1
R1, R2: 330; 0309/12
R3: 1 Mohm; 0309/12
RED-D8: TLLR4400; LED3MM
SPI: MA08-1
TEST: MOMENTARY-SWITCH-SPST-PTH-6.0MM; TACTILE_SWITCH_PTH_6.0MM
U1: PHOTON2

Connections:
GND: ADR1.2, ADR2.2, ADR4.2, C2.2, C3.2, C4.2, C5.2, C6.2, C7.2, C8.2, CONTACT_SENSOR.1, DIGITAL/ANALOG.7, DIGITAL/ANALOG.8, GRN-D9.K (C), I2C.4, I2C.5, IC1.5 (I), IC1.7 (GND), IC1.9 (I), IC1.11 (I), IC1.13 (I), LORA_MODULE.1, RED-D8.K (C), SPI.7, SPI.8, TEST.1, U1.4 (GND)
LI+: U1.28 (LI+)
unnamed: C7.1, CONTACT_SENSOR.2, IC1.1 (I), R3.2, TEST.3 (2)
unnamed: LORA_MODULE.3, U1.15 (TX)
unnamed: GRN-D9.A, R2.1
unnamed: R2.2, U1.19 (D2)
unnamed: R1.2, U1.9 (S4)
unnamed: R1.1, RED-D8.A
unnamed: ADR4.1, U1.22 (D5)
unnamed: IC1.2 (O), IC1.3 (I), POLARITY.3
unnamed: IC1.4 (O), POLARITY.1
unnamed: I2C.2, U1.18 (SCL)
unnamed: ADR2.1, U1.21 (D4)
unnamed: LORA_MODULE.2, U1.14 (RX)
unnamed: I2C.3, U1.17 (SDA)
unnamed: POLARITY.2, U1.25 (D10)
unnamed: ADR1.1, U1.20 (D3)
unnamed: SPI.3, U1.13 (MISO)
unnamed: SPI.4, U1.12 (MOSI)
unnamed: SPI.5, U1.11 (SCK)
unnamed: SPI.6, U1.10 (S3)
unnamed: DIGITAL/ANALOG.2, U1.23 (D6)
unnamed: DIGITAL/ANALOG.3, U1.8 (A5)
unnamed: DIGITAL/ANALOG.4, U1.7 (A2)
unnamed: DIGITAL/ANALOG.5, U1.6 (A1)
unnamed: DIGITAL/ANALOG.6, U1.5 (A0)
VCC: C2.1, C3.1, C4.1, C5.1, C6.1, C8.1, DIGITAL/ANALOG.1, I2C.1, IC1.14 (VCC), LORA_MODULE.5, R3.1, SPI.1, SPI.2, U1.2 (3V3)
VUSB: U1.26 (VUSB)

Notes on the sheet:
GND
TXD
RXD
RST
VDD
N/C
VCC
SCL
SDA
MISO
MOSI
!SS

Board: 2 copper layers, 24 parts (0 on the bottom side), 26 nets, no tracks yet.

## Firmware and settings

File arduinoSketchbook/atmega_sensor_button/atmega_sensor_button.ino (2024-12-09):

/* 
 * Project RangeTestTx
 * Author: Bob Glicksman
 * Date: 4/25/24
 * 
 * Description:  This is code for a tester of LoRa signal range.  The tester is based upon
 *  a Particle Photon that is set up to not need Wifi (any Arduino can be used in its place).
 *  In addition to the Photon, a N.O. pushbutton switch is connected to ground at one end
 *  and Photon pin D0 on the other.  The LoRa module (RYLR998) is connected as follows:
 *  * Vcc to Photon 3.3v
 *  * GND to Photon GND
 *  * Tx to Photon Rx (Serial1)
 *  * Rx to Photon Tx (Serial1)
 *  * Reset is not connected
 * 
 * The testing concept is to produce a companion device - the "hub".  The hub uses its LoRa module
 *  to listen for a message from the tester.  When a message is received, the hub responds with a
 *  message of its own.  If the tester receives the response message, it is still in range of the
 *  hub.
 * 
 * The tester is assigned device number 0 and the hub is assigned device number 1.  The network
 *  number used for testing is 3 and the baud rate to/from the LoRa modem is 115200.  Otherwise,
 *  the default LoRa module values are used.  NOTE:  the tester code does not set up these
 *  values.  The LoRa modules are set up using a PC and an FTDI USB-serial board.
 * 
 * The software senses pressing of the pushbutton and sends a short message to a companion LoRa
 *  module in the hub.  The message is also printed on the Photon's USB serial port for debugging
 *  purposes.  The unit then waits 3 seconds for a response.  If a response is received 
 *  (data received from the hub, beginning with +RCV), the D7 LED is flashed three times.  If no
 *  data is received from the hub (distance too far), the D7 LED is flashed once.
 * 
 * version 1.0; 4/25/24
 */


#define PARTIClEPROCESSOR 0

#if PARTIClEPROCESSOR
#include "Particle.h"
#define DEBUG_SERIAL Serial
#define TPP_LORA_DEBUG 1

#else  // ATmega238
#include "Arduino.h"
#include <NeoSWSerial.h>
#define BUTTON_PIN_DIGITAL 2
#define LED_PIN_DIGITAL 10
#define txPin 11
#define rxPin 12
//#define DEBUG_SERIAL Serial
//#define DEBUG_SERIAL softSerial
#define DEBUG_SERIAL myDebugSerial
NeoSWSerial DEBUG_SERIAL(rxPin, txPin);
//extern SoftwareSerial DEBUG_SERIAL = SoftwareSerial(rxPin, txPin);
#define SENSOR_DEBUG 0  // always 0 for Arduino

#endif

#include "tpp_LoRa.h"

#if PARTIClEPROCESSOR
// The following system directives are to disregard WiFi for Particle devices.  Not needed for Arduino.
SYSTEM_MODE(SEMI_AUTOMATIC);
SYSTEM_THREAD(ENABLED);
#endif

#define VERSION 1.00
#define STATION_NUM 0  // housekeeping; not used ini the code

//#define THIS_LORA_SENSOR_ADDRESS -1 // the address of the sensor

//Jim's addresses
#define THIS_LORA_SENSOR_ADDRESS 12648  // the address of the sensor LoRaSensor
//#define THIS_LORA_SENSOR_ADDRESS 11139 // the address of the sensor  lora3


#if PARTICLEPROCESSOR
// Show system, cloud connectivity, and application logs over USB
// View logs with CLI using 'particle serial monitor --follow'
SerialLogHandler logHandler(LOG_LEVEL_INFO);
#else

#endif

tpp_LoRa LoRa;  // create an instance of the LoRa class


void debugPrint(String message) {
  if (SENSOR_DEBUG == 1) {
    DEBUG_SERIAL.print("sensor: " + message);
  }
}
void debugPrintNoHeader(String message) {
  if (SENSOR_DEBUG == 1) {
    DEBUG_SERIAL.print(message);
  }
}
void debugPrintln(String message) {
  if (SENSOR_DEBUG == 1) {
    DEBUG_SERIAL.println("sensor: " + message);
  }
}

void setup() {

  pinMode(LED_PIN_DIGITAL, OUTPUT);
  pinMode(BUTTON_PIN_DIGITAL, INPUT_PULLUP);

#if PARTICLEPROCESSOR
  blinkTimes(2, 50);
  delay(1000);
  DEBUG_SERIAL.begin(9600);  // the USB serial port
#else
  blinkTimes(4, 50);
  delay(1000);
  pinMode(rxPin, INPUT);
  pinMode(txPin, OUTPUT);
  if (SENSOR_DEBUG == 1) {
    DEBUG_SERIAL.begin(9600);
    delay(250);
    DEBUG_SERIAL.println("Sensor booted and running");
  }

    DEBUG_SERIAL.begin(9600); //xxx
    delay(250);
    DEBUG_SERIAL.println("Sensor booted and running");

#endif

  digitalWrite(LED_PIN_DIGITAL, HIGH);

  int error_code = LoRa.initDevice(THIS_LORA_SENSOR_ADDRESS);
  if (error_code != 0) {  // initialize the LoRa device
    debugPrintln("error initializing LoRa device - Stopping");
    debugPrintln("hint: did you change the LoRaSensorAddress?");
    while (1) {
      blinkTimes(error_code, 100);
      delay(1000);
    };
  };

  if (LoRa.readSettings() != 0) {  // read the settings from the LoRa device
    debugPrintln("error reading LoRa settings - Stopping");
    while (1) {
      blinkTimes(error_code, 100);
      delay(1000);
    };
  };

  debugPrintln("Sensor ready for testing ...\n");
  digitalWrite(LED_PIN_DIGITAL, LOW);

}  // end of setup()


void loop() {

  String receivedData = "";              // string to hold the received LoRa data
  String cmd = "";                       // string to hold the command to send to the LoRa
  static bool awaitingResponse = false;  // when waiting for a response from the hub
  static unsigned long startTime = 0;
  static String lastRSSI = "";
  static String lastSNR = "";
  static int msgNum = 0;

  // test for button to be pressed and no transmission in progress
  if (digitalRead(BUTTON_PIN_DIGITAL) == LOW && !awaitingResponse) {  // button press detected
    digitalWrite(LED_PIN_DIGITAL, HIGH);
    debugPrintln("");
    debugPrintln("--------------------");
    msgNum++;
    String payload = "";
    switch (msgNum) {
      case 1:
        payload = "HELLO m: " + String(msgNum) + " uid: " + LoRa.UID;
        break;
      case 2:
        payload = "HELLO m: " + String(msgNum) + " p: " + LoRa.parameters;
        break;
      default:
        payload = "HELLO m: " + String(msgNum) + " rssi: " + lastRSSI + " snr: " + lastSNR;
        break;
    }
    LoRa.transmitMessage(String(TPP_LORA_HUB_ADDRESS), payload);
    awaitingResponse = true;
    startTime = millis();
    digitalWrite(LED_PIN_DIGITAL, LOW);
  }


  if (awaitingResponse) {

    if (millis() - startTime > 5000) {  // wait 5 seconds for a response from the hub
      awaitingResponse = false;         // timed out
      blinkTimes(1);
      debugPrintln("timeout waiting for hub response");
      msgNum++;  // bump the message number so the hub knows we missed a response
    }
    LoRa.checkForReceivedMessage();
    switch (LoRa.receivedMessageState) {
      case RECEIVE_ERROR_MISSING_RCV:  // error
        awaitingResponse = false;      // error
        blinkTimes(7);
        debugPrintln("error while waiting for response, no RCV");
        msgNum++;
        break;
      case RECEIVE_ERROR_COMMA_COUNT:  // error
        awaitingResponse = false;      // error
        blinkTimes(8);
        debugPrintln("error while waiting for response, bad comma count");
        msgNum++;
        break;
      case 0:      // no message
        delay(5);  // wait a little while before checking again
        break;
      case 1:  // message received
        debugPrintln("received data = " + LoRa.receivedData);
        lastRSSI = LoRa.RSSI;
        lastSNR = LoRa.SNR;

        // test for received data from the hub (denoted by "+RCV")
        if (LoRa.receivedData.indexOf("+RCV") >= 0) {  // will be -1 of "+RCV" not in the string

          awaitingResponse = false;  // we got a response
          debugPrintln("response received");
          DEBUG_SERIAL.println("response: " + LoRa.receivedData);

          if (LoRa.receivedData.indexOf("TESTOK") >= 0) {
            debugPrintln("response is TESTOK");
            blinkTimes(3, 150);
          } else if (LoRa.receivedData.indexOf("NOPE") >= 0) {
            debugPrintln("response is NOPE");
            blinkTimes(4);
            msgNum++;
          } else {
            debugPrintln("response is unrecognized");
            blinkTimes(5);
            msgNum++;
          }
        }
        break;

    }  // end of if(Serial1.available())

  }  // end of if(awaitingResponse)

  //while(digitalRead(D0) == LOW); // wait for button to be released
  //delay(1); // wait a little while before sampling the button again

}  // end of loop()

void blinkTimes(int number) {
  blinkTimes(number, 250);
}

void blinkTimes(int number, int delayTimeMS) {
  for (int i = 0; i < number; i++) {
    digitalWrite(LED_PIN_DIGITAL, HIGH);
    delay(delayTimeMS);
    digitalWrite(LED_PIN_DIGITAL, LOW);
    delay(delayTimeMS);
  }
  return;
}  // end of blinkTimes()

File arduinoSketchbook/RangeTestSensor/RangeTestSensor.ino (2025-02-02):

/* 
 * Project RangeTestSensor
 * Author: Bob Glicksman
 * Date: 4/25/24
 * 
 * Description:  This is code for a tester of LoRa signal range.  The tester is based upon
 *  a Particle Photon that is set up to not need Wifi (an ATmega328 can be used in its place).
 *  In addition to the Photon, a N.O. pushbutton switch is connected to ground at one end
 *  and Photon pin D0 on the other.  On the ATMega a N.O. pushbutton is connected to Vcc at one
 *  end and pin D2 on the other.
 
    The LoRa module (RYLR998) is connected as follows:
 *  * Vcc to Photon 3.3v
 *  * GND to Photon GND
 *  * Tx to Photon Rx (Serial1) (Serial on ATmega)
 *  * Rx to Photon Tx (Serial1) (Serial on ATmega) 
 *  * Reset is not connected
 * 
 *  The testing concept is to produce a companion device - the "hub".  The hub uses its LoRa module
 *  to listen for a message from the tester.  When a message is received, the hub responds with a
 *  message of its own.  If the tester receives the response message, it is still in range of the
 *  hub.
 * 
 * The tester is assigned any device number and the hub is assigned device number 57248, as defined
    in tpp_LoRa.h   (it can be any arbitrary number in the range  0 - 65535).  The network
 *  number used for testing is 18 and the baud rate to/from the LoRa modem is 38400 to be 
    compatible with the ATmega328.  Otherwise,
 *  the default LoRa module values are used.  NOTE:  the sensor code does not set up these
 *  values if run on an ATmega.  The LoRa modules can be set up using a PC and an FTDI USB-serial
    board. If the LoRa module is already set to 38400 baud, then they can be further configured
    by connecting one to a Particle Photon 2 sensor. LoRa modules can also be set up using 
    the Particle Photon 2 hub. 
 * 
 *  The software senses the falling (P2) or rising (ATmega) signal from the pressing of 
    the pushbutton and sends a short message to a companion LoRa
 *  module in the hub.  The message is also printed on the Photon's USB serial port for debugging
 *  purposes.  The unit then waits 3 seconds for a response.  If a response is received 
 *  (data received from the hub, beginning with +RCV), the Green LED (onboard D7 of the Photon) 
    is flashed three times.  If no
 *  data is received from the hub, the Green LED (onboard D7 of the Photon) is flashed once.
 * 
 * version 2.0; 4/25/24

    20241212 - version 2. works on Particle Photon 2 
    v 2.1 pulled all string searches out of if() clauses
    v 2.2 #define for continuous test mode
    v 2.3 works on ATmega328
    v 2.4 integrates ATmega power down code
    v 2.5 now calls setAddress for the LoRa module in setup
    v 2.6 processes address jumper pins to alter the sensor device address
    v 2.7 address lines work for P2
    v 2.8 #define to not wait for hub response
    v 2.9 messages are now shorter
    v 2.10 added a reset flashing message
           reports on CRFOP in transaction 2
           reads LoRa settings in setup
 */

#include "tpp_LoRaGlobals.h"


#include "tpp_loRa.h" // include the LoRa class

#define CONTINUOUS_TEST_MODE 0 // set to 1 to enable continuous testing
#define WAIT_FOR_RESPONSE_FROM_HUB 1 // set ot 0 to disable waiting for a response from the hub

// The following system directives are to disregard WiFi for Particle devices.  Not needed for Arduino.
#if PARTICLEPHOTON
    SYSTEM_MODE(SEMI_AUTOMATIC);
    SYSTEM_THREAD(ENABLED);
    // Show system, cloud connectivity, and application logs over USB
    // View logs with CLI using 'particle serial monitor --follow'
    // SerialLogHandler logHandler(LOG_LEVEL_INFO);
#else
    // ATMega328
    #include <avr/sleep.h>  // the official avr sleep library
    #include <avr/io.h>
    #include <avr/interrupt.h>
#endif

#define VERSION 2.9
#define STATION_NUM 0 // housekeeping; not used ini the code

#define LORA_TRIP_SENSOR_ADDRESS_BASE 5 // the base address of the trip sensor type

//Jim's addresses
//#define THIS_LORA_SENSOR_ADDRESS 12648 // the address of the sensor LoRaSensor
//#define THIS_LORA_SENSOR_ADDRESS 11139 // the address of the sensor  lora3

tpp_LoRa LoRa; // create an instance of the LoRa class

// module global scope for mimimal string memboery allocation
int mglastRSSI = 0;
int mglastSNR = 0;
bool mgFatalError = false;
volatile bool mgButtonPressed = false;  // set true in the ISR_buttonPressed() function
String mgpayload;
String mgTemp;

// all debug prints through here so it can be disabled when ATmega328 is used
void debugPrintln(const String message) {
    #if PARTICLEPHOTON
        DEBUG_SERIAL.println(message);
    #endif
}

// blinkLED(): blinks the indicated LED "times" number of times
void blinkLED(int ledpin, int number, int delayTimeMS) {
    digitalWrite(ledpin, LOW);
    delay(100);
    for(int i = 0; i < number; i++) {
        digitalWrite(ledpin, HIGH);
        delay(delayTimeMS);
        digitalWrite(ledpin, LOW);
        delay(delayTimeMS);
    }
    return;
} // end of blinkLED()

// blinkLEDsOnERROR() blinks red led fast Where times and then slow ErrNum times
//    then repeats. Never exits.
void blinkLEDsOnERROR(int whereTimes, int errNum){
    while(1) {
        blinkLED(RED_LED_PIN, 1, 1000);
        delay(250);
        blinkLED(RED_LED_PIN, whereTimes, 150);
        delay (500);
        blinkLED(RED_LED_PIN, errNum, 250);
        delay (500);
        blinkLED(GRN_LED_PIN,2,150);
        delay(250);
    }
}

// blinkLEDsOnBoot() blinks the LEDs to indicate the system is booting
void blinkLEDsOnBoot() {
    digitalWrite(GRN_LED_PIN, LOW);
    digitalWrite(RED_LED_PIN, LOW);
    delay(100);
    for(int i = 0; i < 3; i++) {
        digitalWrite(GRN_LED_PIN, HIGH);
        digitalWrite(RED_LED_PIN, HIGH);
        delay(150);
        digitalWrite(GRN_LED_PIN, LOW);
        digitalWrite(RED_LED_PIN, LOW);
        delay(100);
    }
    return;
}

// blinkLEDsOnReset() blinks the LEDs to indicate the system is resetting
void blinkLEDsOnReset(int timesToBlink) {
    digitalWrite(GRN_LED_PIN, LOW);
    digitalWrite(RED_LED_PIN, LOW);
    delay(100);
    for(int i = 0; i < timesToBlink; i++) {
        digitalWrite(GRN_LED_PIN, HIGH);
        digitalWrite(RED_LED_PIN, HIGH);
        delay(150);
        digitalWrite(GRN_LED_PIN, LOW);
        digitalWrite(RED_LED_PIN, LOW);
        delay(150);
    }
    digitalWrite(GRN_LED_PIN, LOW);
    digitalWrite(RED_LED_PIN, LOW);
    delay(1000);
    return;
}

void ISR_wakeAndSend() {
    #if (PARTICLEPHOTON)
        // nothing special to do
    #else
        // ATMega328
        sleep_disable();  // cancel sleep mode for now
        detachInterrupt(digitalPinToInterrupt(BUTTON_PIN));  // preclude more interrupts due to bounce, or other
    #endif
    mgButtonPressed = true;
}
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

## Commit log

2024-05-04 Added code for low power testing
2024-05-04 Create LoRa Module Low Power Testing Report.pdf
2024-05-05 Create Battery power calculations.xlsx
    Calculation of battery life assuming use of an Attiny85 microcontroller and a reset pulse generator circuit based upon 74HC1322 IC
    [Battery power calculations.xlsx]
2024-07-07 changes to make sensor report more quickly
2024-07-10 hub responds with error messages; sensor blinks them out
    [LoRaRangeTestHub.ino, RangeTestSensor.ino]
2024-08-04 Added ATmega328 low power testing code
    Changed the folder name for the LoRa module low power testing to make this clear. Added folder for Arduino code that tests low power code for ATmega328.
2024-08-05 Update Interrupt_Test2_Low_Power.ino
    Changed to use external pullup rather than internal pullup. Quiescent power supply draw when contact is closed is reduced from 85 microamps to about 3.4 microamps.
2024-08-06 device address now used by hub. clean up in tpp_LoRa.cpp
2024-08-07 moved to current tpp library
2024-08-07 update to current version
2024-08-08 small bug affecting payload of first message
    [tpp_LoRa.cpp]
2024-08-08 better handling of start up errors
    [RangeTestSensor.ino, tpp_LoRa.cpp]
2024-08-08 new tpp_lora, better start up error handling
    [LoRaRangeTestHub.ino, tpp_LoRa.cpp]
2024-08-08 better error handling on startup
    [RangeTestSensor.ino]
2024-08-10 fix to work with Photon 1
    [tpp_LoRa.cpp]
2024-08-11 added a busy flag to help with multiple active sensors
2024-08-12 Create Basic_ATmega328_LoRa_test.ino
    This is essentially the same test that was performed using a Photon on 5/24. It now uses the bare bones ATmega328. It powers up and down the LoRa module but does not power down the ATmega328 chip.
2024-08-12 Update Basic_ATmega328_LoRa_test.ino
    Added another LoRa power up command to ensure that we get a +OK response after LoRa power down
2024-08-14 Create Low_power_ATmega328_LoRa_integration.ino
    Version 1.0 of integration of microcontroller low power and LoRa into a functionaing contact clouse sensor.
2024-08-14 set radio power explictly; log RSSI
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2024-09-14 hub receives message ok but sensor blinks 7 error on answer from hub
    [atmega_sensor_button.ino, tpp_LoRa.cpp]
2024-09-22 hub gets good msg, sensor does not get RCV from LoRa
2024-10-26 Development PCB
    Added a HARDWARE folder and placed design for a development board PCB into this folder. Eagle CAD files and manufacturing files are all included.
    [DRILEGEND.CFG, LoRa_Sensor.brd, LoRa_Sensor.sch]
2024-11-02 Dev PCB Photos
    The Dev PCB is shown assembled and in a successful test configuration.
2024-11-03 Update Low_power_ATmega328_LoRa_integration.ino
    Added support for both red and green LEDs.
2024-11-15 d0 is now used to set lora device address on boot
2024-12-06 works on P2 sensor
2024-12-06 still works on P2 sensor
2024-12-09 Added Arduino code
    Added the 4 files to a folder called RangeTestSensor inside of the arduinoSketchbook folder. The code does not compile because of #if and if() statements which should probably be #ifdef statements, b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
2024-12-09 Update tpp_LoRaGlobals.h
    Fixed the #define issue in the globals file. Now the code compiles!
    [tpp_LoRaGlobals.h]
2024-12-12 LoRa power down works on ATMega
2024-12-12 more low power, works on P2
2024-12-12 button press is now an ISR. Works on P2
2024-12-15 final changes to low memory. note no LoRa powerdown
2024-12-16 Version 1.30
    Changed the sensor trip message to be short and to have a one-up message number (mod 10) so that we can detect messed messages at the hub or upstream thereof.
2024-12-16 Update Low_power_ATmega328_LoRa_integration.ino
    Changed reserved buffer size to 32 - counted wrong before.
    [Low_power_ATmega328_LoRa_integration.ino]
2024-12-18 version 1.40
    Added computation and setting of the LoRa module device address based upon a defined base address + offset; the offset being determined by 3 jumpers (Arduino pins 12, 11, 10 as MSB - LSB). Also used 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
2024-12-19 Created a Photon Based Tester
    This tester uses the TPP Wireless I/O Board to stress test the LoRa sensor. The relay on the Wireless I/O Board is closed and opened a pre-determined number of times. The Hub logs the received messag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
2024-12-19 Update LoRa_Sensor_Tester.ino
    Changed to run 1000 sensor trips for stress testing.
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2024-12-22 Added support for address jumpers
    Address jumpers are now processed in the code. Changed setAdrress() argument type to unsigned int in all files. Added pin definitions to globals.h file.
    This code should work on the Photon 2 as well as on Arduino, but it has only been tested on Arduino. These files need to be copied into the VS locations for Photon.
2024-12-25 Test version 2.6.1 of Arduino
    Added sending a reset test message at the end of setup() so that any resets during stress testing will be logged. This is temporary code for stress testing the production sensor code on ATMega328 only. No #defines or such are included for the Photon version. This code is intended to run ONLY on an ATMega328 based sensor and only for stress testing purposes.
    [LoRa_Sensor_Tester.ino, RangeTestSensor.ino]
2024-12-26 messages are now short
    [LoRaRangeTestHub.ino, RangeTestSensor.ino, tpp_LoRa.cpp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]
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2024-12-28 Set ATMega328 Sensor to not wait for response
    Only change is to defined constant for testing with no waiting for a response from the hub.
2025-01-10 Rev A PCB files added
    [DRILEGEND.CFG, LoRa_Sensor.brd, LoRa_Sensor.sch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]
2025-01-16 Update tpp_LoRaGlobals.h
    Changed the Address jumper pins to correspond to the rev A1 pcb.
2025-01-17 resolved P2 issue with debug printing
    [LoRaRangeTestHub.ino, tpp_LoRa.cpp, tpp_LoRaGlobals.h]
2025-01-26 P2 based hub code fixes
    I changed the pin definitions to the latest spec. Also corrected typo in #include. Pin changes in tpp_LoRaGlobals.h. Typo change in RangeTestSensor.ino.
    [RangeTestSensor.ino, tpp_LoRaGlobals.h]
2025-01-26 Added Eagle file for Photon 2 PCB
    These files are preliminary. The board layout is not done.
    [LoRa_Photon2.brd, LoRa_Photon2.sch]
2025-02-01 Added Photon 2 PCB
    Added Eagle files, schematic pdf and rendering of the board to the Hardware folder.
    [LoRa_Photon2.sch]
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2025-02-18 Minor changes to schematic
    Only changed labels on schematic. Does not alter the netlist or the board layout.
    [LoRa_Photon2.sch]
2025-03-15 Rev B PCB
    Rev B PCB is complete and off to manufacturing. This board is a little longer than Rev A, but should otherwise be mechanically compatible. It includes an onboard battery.
    [LoRa_Sensor_RevB.brd, LoRa_Sensor_RevB.sch]
2025-04-09 changed default CFROP
    Is was set as 10; should be 22 for max power. Changed to 22.
2025-04-18 added case 3D files
    [Bottom square.stl, LoRaHubCase.stl, LoRa_Hub_Case.f3d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]
2025-06-07 Version 3.0
    Added a cloud function to send simulated sensor events to the Particle cloud. Also added a cloud variable to read out the current code version for maintenance purposes.
2025-06-24 help button case
    [PCB Mount-2025-04-25-1.step, Wall Mount-2025-04-25-1.step]
2025-06-25 Updated Admin App
    Added additional buttons and deviceIDs

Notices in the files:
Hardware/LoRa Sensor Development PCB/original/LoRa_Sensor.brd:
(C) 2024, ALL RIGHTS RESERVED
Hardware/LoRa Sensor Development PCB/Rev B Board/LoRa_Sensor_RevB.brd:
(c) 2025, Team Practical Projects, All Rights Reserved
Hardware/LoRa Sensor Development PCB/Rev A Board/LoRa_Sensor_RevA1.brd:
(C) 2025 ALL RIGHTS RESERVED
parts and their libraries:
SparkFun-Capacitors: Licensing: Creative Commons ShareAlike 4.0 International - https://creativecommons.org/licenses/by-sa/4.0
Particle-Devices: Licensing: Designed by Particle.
